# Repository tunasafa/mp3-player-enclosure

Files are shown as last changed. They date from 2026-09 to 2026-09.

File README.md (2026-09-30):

# mytunas — MP3 player enclosures

> *I got tired of renting my music.*

This repository contains **two current enclosure models** for the same offline MP3 player project. Both are fit and mechanical prototypes; physical hardware qualification, electronics integration and production release are still outstanding.

## Current models

| Model | Controls and display | Exterior | Current files |
|---|---|---:|---|
| **P04 clickwheel player** | 4th-generation monochrome clickwheel, 2.0-inch landscape display, Adafruit #6309 headphone output | **115 × 60 × 12.9 mm** | [Model README](revision_04/README.md) · [interactive viewer](https://tunasafa.github.io/mp3-player-enclosure/revision_04/preview.html) |
| **Model 02 touchscreen player** | 2.4-inch landscape capacitive touchscreen, two battery allocations, Adafruit #6309 headphone output | **64 × 128 × 8.3 mm** | [Model README](touchscreen_02/README.md) · [interactive viewer](https://tunasafa.github.io/mp3-player-enclosure/touchscreen_02/preview.html) |

The P04 branch uses two printed shells, a protected 503040 battery allocation and the intact DAC with its headphone socket. Model 02 uses the M02-03 metal finish, a continuous PA12 frame, a welded display carrier, removable board supports and the DAC jack at the bottom. The detailed model pages are the source of truth for dimensions, parts, evidence and remaining checks.

## P04 clickwheel player

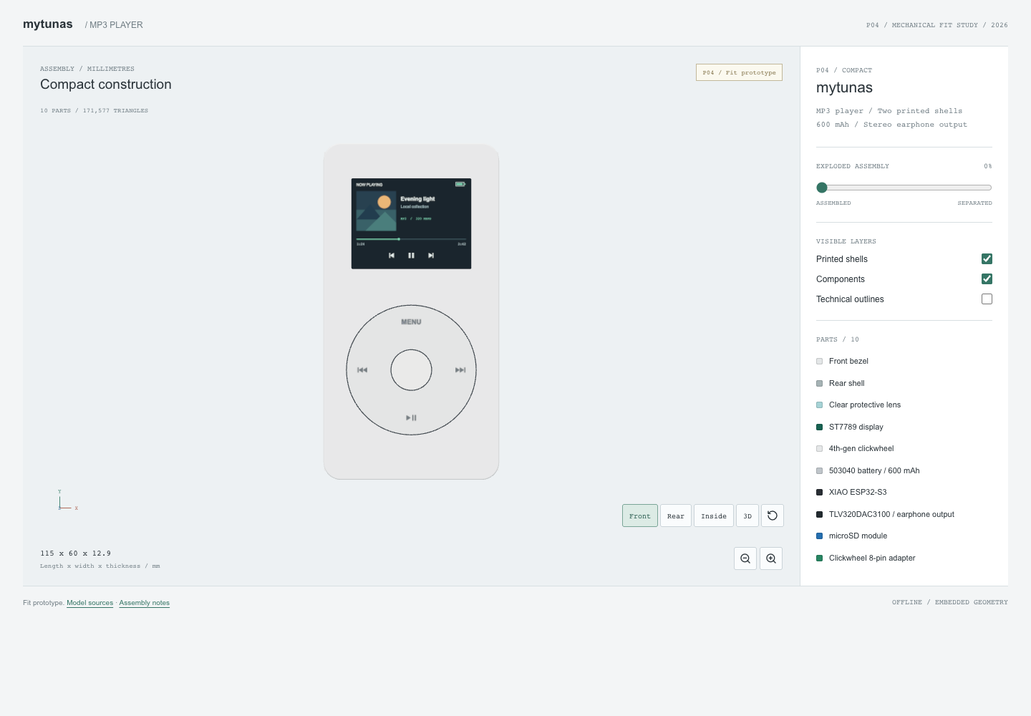
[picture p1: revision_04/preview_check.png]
P04 clickwheel player interactive preview


**[Open the P04 interactive 3D viewer](https://tunasafa.github.io/mp3-player-enclosure/revision_04/preview.html)**

The P04 layout keeps the 600 mAh battery below the display, behind the wheel. The DAC is at the upper left, flipped relative to the earlier layout, with its components toward the rear and its headphone socket at the top. USB and microSD use close-fitting side openings. These openings and the shell seam are unsealed; no IP rating is claimed.

Read the [P04 model notes](revision_04/README.md), [hardware and connection notes](revision_04/HARDWARE_NOTES.md), [BOM](revision_04/BOM.csv), [validation report](revision_04/validation.json) and [dimensioned overview](revision_04/design_overview.pdf). Print files are under [`revision_04/designs/P04_compact/STL/`](revision_04/designs/P04_compact/STL/).

## Model 02 touchscreen player

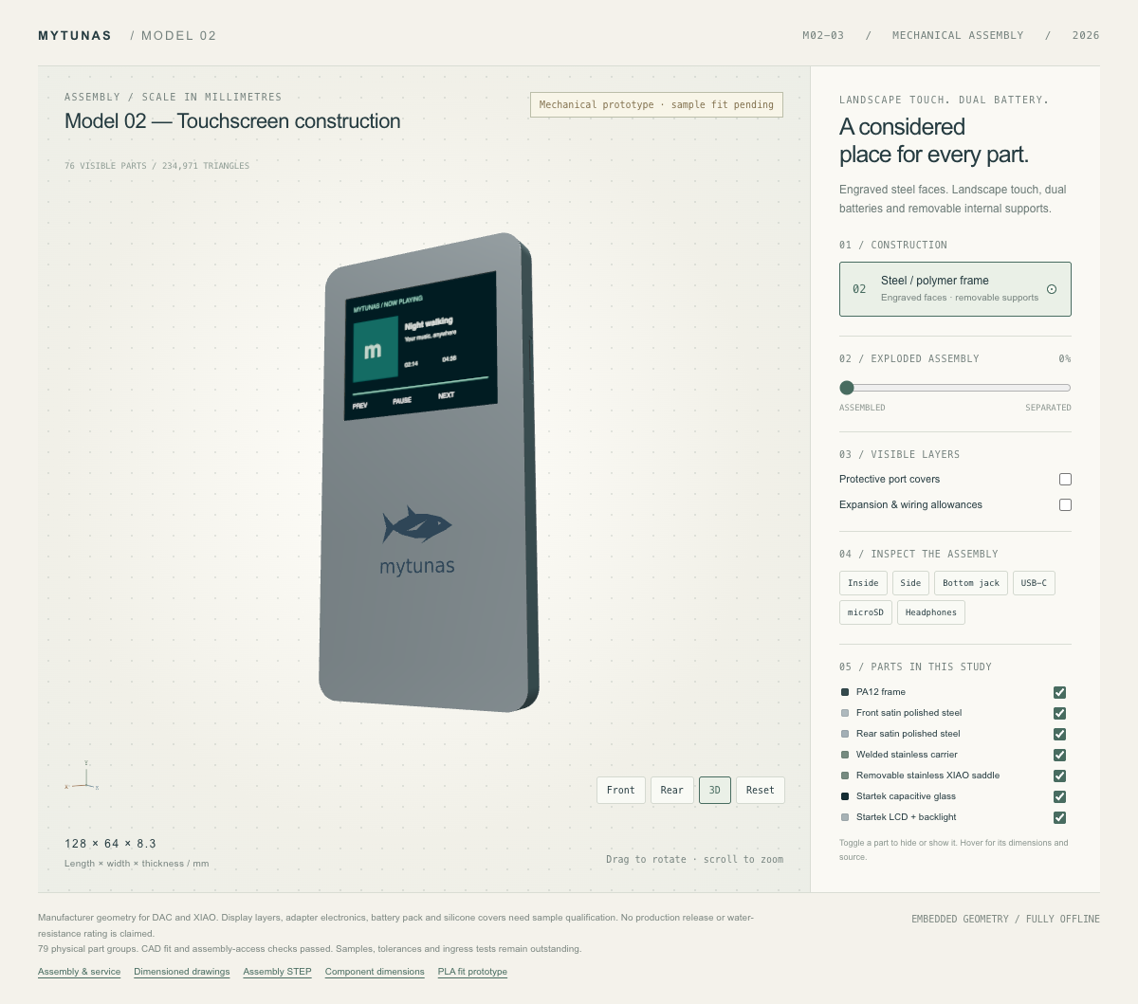
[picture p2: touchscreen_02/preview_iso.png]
Model 02 touchscreen player interactive preview


**[Open the Model 02 interactive 3D viewer](https://tunasafa.github.io/mp3-player-enclosure/touchscreen_02/preview.html)**

The current M02-03 layout uses the 2.4-inch Startek touchscreen allocation, two battery envelopes in an L arrangement, the intact Adafruit DAC with its original jack at the bottom, engraved steel faces, a welded internal carrier and serviceable supports. The screen sample, combined 1S2P battery, interface PCB and physical tolerances remain to be qualified. The port covers are prototype references, so no water-resistance rating is claimed.

Read the [Model 02 notes](touchscreen_02/README.md), [assembly and service sequence](touchscreen_02/ASSEMBLY.md), [component evidence](touchscreen_02/COMPONENT_DIMENSIONS.md), [release checklist](touchscreen_02/RELEASE_CHECKLIST.md), [BOM](touchscreen_02/BOM.csv), [validation report](touchscreen_02/validation.json) and [dimensioned drawings](touchscreen_02/drawings.pdf).

The [M02-P01 PLA fit prototype](touchscreen_02/pla_fit/README.md) is a separate MK3S+ branch with the same exterior and component positions, four printed assembly parts and two releasable snaps. [Open the PLA assembly](touchscreen_02/pla_fit/preview.html) or [download the unsliced print plate](touchscreen_02/pla_fit/M02-P01_MK3S_PLA_UNSLICED.3mf). Physical printing and latch fit remain to be tested.

## Why this exists

Every month, another €10 disappears into a streaming service that decides what I can listen to, when, and on which devices. Skip limits, offline restrictions, algorithms picking songs for me, entire albums vanishing from catalogs overnight because some licensing deal fell through. And if I ever stop paying? Everything is gone.

I used to *own* music. I had files. I had albums. I could play them on whatever I wanted, wherever I wanted, forever. No subscription. No internet required. No corporation standing between me and a song.

So I'm building my own player: a physical device with a screen, a clickwheel or touchscreen, a headphone jack and a microSD card full of music that belongs to me. No accounts, no telemetry, no monthly fee.

## Repository map

```text
revision_04/       P04 clickwheel player; current compact printed-shell branch
touchscreen_02/    Model 02 touchscreen player; current M02-03 mechanical branch
touchscreen_01/    Superseded T02 touchscreen prototype and hardware audit
touchscreen_metal/ T03 construction reference and packing studies
```

The historical touchscreen branches are retained to document design decisions. Their dimensions, parts and validation reports do not replace the two current model pages above. The `revision_04/studies/` folders likewise contain rejected or conditional P04 experiments.

## Rebuild

Each model has its own rebuild and validation instructions. The short forms below assume the repository's existing `.venv` and Node dependencies:

```sh
# P04 clickwheel player
.venv/bin/python revision_04/build.py
.venv/bin/python revision_04/make_viewer.py
node revision_04/verify_viewer.mjs

# Model 02 touchscreen player
.venv/bin/python touchscreen_02/build.py
.venv/bin/python touchscreen_02/verify_fit.py
node touchscreen_02/verify_viewer.mjs
```

The generated viewers are standalone HTML files and can be opened locally. GitHub's source-file view does not run them; use the Pages links or download the HTML first.

## Project status

The CAD and browser checks validate digital geometry, mesh validity, clearances and viewer behavior. They do not prove purchased-component fit, flex routing, electrical compatibility, battery safety, structural durability, ingress protection or production readiness. See the [P04 status](revision_04/README.md#status) and [Model 02 release gates](touchscreen_02/RELEASE_CHECKLIST.md) before fabricating parts.

This is a personal hardware design project. Third-party CAD attribution and license notes are kept with each model's `vendor/` directory.

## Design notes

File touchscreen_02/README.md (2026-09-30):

# Model 02 — current serviceable touchscreen player

**One of the two current enclosure models.** The other is [P04, the clickwheel player](../revision_04/README.md).

**PLA fit-prototype branch:** [M02-P01 print/assembly instructions](pla_fit/README.md) · [interactive screwless assembly](pla_fit/preview.html) · [MK3S+ print plate](pla_fit/M02-P01_MK3S_PLA_UNSLICED.3mf). This separate branch keeps the 64 × 128 × 8.3 mm envelope and component positions, using four printed parts and two release snaps. The M02-03 metal design below remains the reference; PLA snap performance still needs a coupon trial.

**64 × 128 × 8.3 mm**, with the 2.4-inch landscape touchscreen, two battery allocations and the intact Adafruit DAC's original headphone jack at the bottom. M02-03 uses the T03 metal finish, original bluefin engravings and mechanically removable supports in the nominal enclosure assembly.

[Interactive viewer after GitHub Pages deployment](https://tunasafa.github.io/mp3-player-enclosure/touchscreen_02/preview.html) · [Local/offline viewer](preview.html) · [Dimensioned drawing set](drawings.pdf) · [Assembly STEP](designs/M02_03/assembly_NOMINAL.step) · [Every part's measurements](measurements.csv) · [Validation](validation.json)

The mechanical prototype includes engraved steel faces, a continuous polymer frame, 13 metal threaded insert seats, a welded steel display carrier with cross ribs and access windows, a two-screw XIAO saddle, rear-fastened steel DAC columns with insulating locating seats, battery guides, insulating pads, SD and display-interface mounting lands, gaskets and flush removable port-cover prototypes. The viewer uses the same physical geometry as the CAD checks and STEP export.

**This is not a production release.** The display drawing/flex and final battery pack have not been qualified; the interface PCB is not routed. Physical tolerances, retention, plate deflection, charging and ingress still require testing. The [release checklist](RELEASE_CHECKLIST.md) makes these remaining steps explicit. Detailed geometry is not evidence that these tests have passed.

## Files to use

| Deliverable | Purpose |
|---|---|
| `designs/M02_03/assembly_NOMINAL.step` | Current assembly, physical parts only |
| `designs/M02_03/reserved_spaces_REFERENCE.step` | Unoccupied expansion and routing allocations; never manufacture these solids |
| `designs/M02_03/*.step` | Individual case, support and cover geometry |
| `designs/M02_03/STL/midframe_BEFORE_HEAT_INSERTS_PA12_FIT_PROTOTYPE.stl` | Frame before insert installation, with 2.15 mm pilots, positioned on Z0 |
| `designs/M02_03/midframe.step` | Installed frame with polymer displaced around inserts; do not use as the pre-installation print |
| `designs/M02_03/STL/*METAL_REFERENCE.stl` | Metal shape references; not thin plastic print instructions |
| `designs/M02_03/STL/*SILICONE_REFERENCE.stl` | Installed/compressed cover references; retention/mold design unqualified |
| `designs/M02_03/profiles/*.dxf` | Millimetre profiles for specifically named flat layers; rear profile is before countersinking |
| `drawings.pdf`, `measurements.csv`, `BOM.csv` | Dimensions, coordinates, materials and part status |
| `ASSEMBLY.md` | Installation and service sequence, including board insertion paths |
| `COMPONENT_DIMENSIONS.md` | Evidence and uncertainty for bought and custom parts |
| `assets/front_engraving.svg`, `assets/rear_engraving.svg` | Original vector engraving artwork in face coordinates |

`packing_REFERENCE_ONLY.step` remains a compatibility alias for the current complete assembly. The GitHub source-file view will not run an HTML viewer; open the Pages link or the downloaded HTML in a browser.

The explosion slider, part toggles, covers and routing allowances preserve your current rotation, pan and zoom. Resizing the window also preserves the camera position. Choose a view preset or Reset when you want to reframe the assembly.

The current preview uses T03's darker metal palette and surface response, with the M02-03 engravings retained. This appearance setting is defined in `viewer.js`; it does not change the validated geometry.

## Dimensions and retention

| Feature | Current allocation |
|---|---|
| Exterior | 64.00 × 128.00 × 8.30 mm; R6 corners |
| Front and rear metal | 0.40 mm stainless each |
| Perimeter frame | Z0.55–7.75; raised rear compression stops to Z7.90; 1.60 mm walls |
| Display carrier | 59 × 50 mm; 0.20 mm web and 0.30 × 1.25 mm welded blades; four M1.4 × 3 screws |
| Main fasteners | Seven M1.6 × 5 nominal countersunk screws into PEM MSIB-M1.6-300 insert allocations |
| Internal threads | Six PEM MSIB-M1.4-150 insert allocations for carrier and XIAO saddle |
| DAC attachment | Three custom threaded steel columns and insulating locating seats; three rear M1.4 × 3 countersunk screws |
| Engravings | 0.03 mm nominal depth on front and rear; original tuna mark and model/revision text |
| Battery A | 37 × 25.5 × 5.2 mm; centre X−10.5, Y−6; underside Z0.70 |
| Battery B | 25.5 × 37 × 5.2 mm; centre X−15.75, Y−40.5; underside Z0.70 |
| Battery rear allowance | 1.93 mm to liner; 1.70 mm reserved for expansion |
| DAC | Original manufacturer STEP rotated −90° around Z; full published 7.1 mm height retained |
| DAC rear clearance | 0.18 mm to dielectric liner |
| USB-C mouth | X31.6000, Y−9.9927, Z3.6050; exact Seeed rim plus 0.15 mm radial allowance |
| Jack mouth | X18.8592, Y−63.6000, Z4.4225; 5.00 mm case aperture |
| SD mouth | X−31.6000, Y29.0000, Z6.4000; 11.50 × 1.50 mm slot |

There are no straps across the pouches. Separate replaceable insulating adhesive pads retain the batteries, and frame rails provide lateral clearance. The DAC rests on a removable dielectric sheet; its original holes receive insulating locating seats under rear-fastened steel columns. The XIAO rests on a removable dielectric seat and is held by a two-screw steel saddle with a shield cushion. The small removable XIAO side stop still uses a replaceable adhesive pad.

The revised carrier replaces four glued rib/bond parts with a connected welded steel structure. Its four screws and the two saddle screws use metal insert threads. [PEM MSIB-M1.6-300](https://www.pemnet.com/products/product-finder/msib-m1-6-300/) and [MSIB-M1.4-150](https://www.pemnet.com/products/product-finder/msib-m1-4-150/) have published 2.5 mm nominal outside diameters and 2.15 mm installation holes. The CAD uses smooth dimensional envelopes; actual knurls and thread helices are omitted. Supplier installation forces measured in other plastics do not establish PA12 performance. Qualify the chosen frame process, insert installation and torque on coupons.

These changes provide defined retention and service access; they do not establish a multi-year lifetime. Batteries, display bonding and the provisional SD/interface boards still need replaceable adhesive interfaces. XIAO withdrawal requires removing battery A first because the inward USB withdrawal path crosses its installed envelope. See the explicit service order rather than assuming every board lifts out independently.

## Display and electronics evidence

Startek lists [KD024QVFMA020-C003A](https://www.startek-lcd.com/product/474-KD024QVFMA020-C003A-2.4-inch-240x320-ST7789V-IPS-LCD-module-with-build-in-capacitive-touch-panel.html) as a 240 × 320 IPS panel with ST7789V, FT6336G touch, a 42.92 × 60.26 × 3.75 mm total outline, a 45-pin 0.5 mm LCD flex, 3.3 V module input and an 80 mA backlight. Its touch specification lists a 42.62 × 59.96 × 1.25 mm G+F assembly. The model uses that touch outline and the remaining 2.50 mm for the LCD. Adhesive split, active-area offset, maximum tolerances and actual folded tails still require the supplier drawing. The product-page drawing link returned 404 during this work; the available stock-policy image is not a mechanical drawing.

The 45-pin interface replaces the inappropriate 15-pin watch connector allocation. A larger 15 × 32 mm interface board is allocated behind the screen, with a 45-pin ZIF envelope. Its schematic and PCB layout are not complete. The SD board/socket also remain conservative custom-board allocations. These electronic assemblies must be completed before ordering the enclosure as production tooling.

Startek's [general sales policy](https://www.startek-lcd.com/?no=1) allows small orders; this is not confirmation of current stock for the exact suffix. The [supplier inquiry](SUPPLIER_INQUIRY.md) remains unsent.

## Battery and power

The cell allocations use the published maximum finished-pack dimensions for DTP502535, referenced by [SparkFun PRT-13851](https://www.sparkfun.com/lithium-ion-battery-400mah.html) and its [manufacturer drawing](https://www.digikey.com/htmldatasheets/production/2065026/0/0/1/prt-13851.pdf). Two 400 mAh-class cells suggest an **800 mAh target**. A supplier-designed matched **1S2P** pack, its protection and its final lead layout are still required. The model is not an instruction to connect two retail protected packs together.

Confirm the chosen pack against the XIAO charger, temperature limits, charge termination and operation while charging. The XIAO's supported battery input is a single rechargeable 3.7 V lithium cell/parallel group; do not use a two-cell series pack. [Seeed battery documentation](https://wiki.seeedstudio.com/xiao_esp32s3_getting_started/).

The metal enclosure has no qualified RF path. Wi-Fi/Bluetooth antenna placement and performance are outside this mechanical release; the default design is a local SD-based player. Touch wake, power-off behavior and battery measurement also need firmware/electrical verification.

## Ports and sealing

All three case apertures are physically cut and aligned to their corresponding component mouths. USB follows the actual eight-edge Seeed rim with 0.15 mm radial clearance; the 5.00 mm jack opening allows 0.20 mm around the CAD flange; the SD slot allows 0.25 mm per side around the card. Zero-clearance fits are not specified: they would not accommodate real manufacturing variation. Blind internal pockets accommodate the connector bodies while preserving an exterior lip. Flush silicone-cover prototypes close the ports without extending the exterior dimensions. The viewer starts with covers removed and provides dedicated USB-C, SD and jack closeups. Fit the covers with the checkbox when reviewing the closed enclosure.

The covers are modeled in their installed/compressed shape, with separate recessed sealing lands. Their thin flanges, retention, free-state dimensions, material hardness and mold process have not been validated. They are prototype references, not proven waterproof plugs. The XIAO USB socket and Adafruit headphone jack are not established as sealed receptacles. **No IP or water-resistance rating is claimed**, especially with any cover removed.

## Verification and rebuild

The build checks all modeled physical-part intersections, all reservation collisions, exterior containment, unobstructed case ports with covers removed, rear loading of the display and batteries, sampled recessed/lowered/sliding board insertion, screwdriver access, nominal support contact, and valid single-body watertight structural/cover meshes. Deliberate collision and blocked-port probes test failure detection. Browser tests check the same CAD mesh bounds and physical mesh counts, inside/outside views, exploded assembly, covers, mobile rendering and the old viewer redirect.

From the repository root, using the existing CadQuery environment and `revision_04` npm dependencies:

```sh
.venv/bin/python touchscreen_02/make_branding.py
.venv/bin/python touchscreen_02/build.py
.venv/bin/python touchscreen_02/verify_fit.py
.venv/bin/python touchscreen_02/make_drawings.py
node touchscreen_02/verify_viewer.mjs
.venv/bin/python touchscreen_02/package_design.py
```

A failed build writes its report and refuses new CAD/viewer exports. Manufacturing release depends on the checklist, not just `validation.json` reporting a nominal fit.

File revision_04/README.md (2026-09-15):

# mytunas / P04 — current clickwheel player

**One of the two current enclosure models.** The other is [Model 02, the touchscreen player](../touchscreen_02/README.md).

**115 x 60 x 12.9 mm enclosure**, 0.2 mm thinner than the 13.1 mm baseline, with no footprint increase. The selected hardware is unchanged. The protected 600 mAh battery is entirely below the display, behind the wheel. The DAC is at the upper left, flipped 180 degrees about Y relative to the original 13.1 mm layout, with its components facing the rear and headphone socket at the top.

Open [the interactive preview](preview.html), [component layout](internal_layout.png), or [shell drawings](design_overview.pdf). See [BOM](BOM.csv), [hardware notes](HARDWARE_NOTES.md) and [model sources](vendor/README.md).

The detached-jack experiment has been withdrawn from this build: it added wiring and retention without reducing the complete case. The intact DAC and onboard socket are restored. See [thickness decision and thinner-battery candidate](THICKNESS_REVIEW.md) for the two limiting stacks and the conditions under which a future change would help.

## Thin arrangement

| Item | Current allocation |
|---|---|
| Battery | 40 x 30 x 5 mm; center (0, -8), Z 5.0-10.0; below LCD |
| DAC | 25.4 x 33.7 x 7.1 mm; center (-9.3, 40.763), Z 4.3-11.4 |
| XIAO | Upper right, center (17.996, 30), Z 4.3; USB mouth nominally flush |
| microSD | Lower right, center (17.7, -36), Z 5.0 |
| Wheel adapter | Lower left, center (-13, -37), Z 5.0 |
| Battery connector | Above/right of battery, center (18, 15.5) |

The battery's top edge is Y7 and the LCD's bottom edge is Y10, so they do not overlap in projection. The full 5 mm cell thickness and the **original 1.7 mm rear allowance** are retained. No battery space was traded away to obtain the new thickness.

A 0.2 mm-deep local LCD seating pocket leaves **1.0 mm of front skin** beneath its perimeter. The LCD sits at Z1.2 instead of Z1.4, preserving 0.2 mm adhesive space and 0.5 mm to the lens. The complete wheel moves forward 0.2 mm, retaining 0.2 mm beneath its backing. Its representative center button is about 0.06 mm proud of the front: shell depth is 12.9 mm, illustrated button-to-back span about 12.96 mm. Exact wheel geometry remains unmeasured.

The two limiting stacks are now:

- LCD: front Z1.2 + 2.8 LCD + 0.3 gap + 7.1 DAC + 0.3 gap + 1.2 rear skin = **12.9 mm**.
- Wheel: front Z1.4 + 3.3 backing + 0.3 gap + 5.0 cell + 1.7 rear allowance + 1.2 skin = **12.9 mm**.

The DAC still shares the upper LCD area. Behind the thicker wheel it would require 13.6 mm even with the new seat. The rotated board alone cannot reduce its height. Both face orientations were checked at the upper location; the released version is rear-facing as requested. It retains the [manufacturer's published 7.1 mm height](https://www.adafruit.com/product/6309), rather than substituting the smaller nominal STEP height of 6.3725 mm.

These are lower bounds for this layered arrangement and the retained allowances, not a proof of globally optimal packing. Further reductions need measured component maxima, revised allowances or a different enclosure architecture. No board trimming, connector removal, battery compression or electrical substitutions are made.

The original and older compact comparison baselines remain in the repository. `validation.json.requested_repack` compares against both the 13.1 mm target and the rejected 13.8 mm battery-behind-display version. The older `studies/dac_orientation/` folder is historical and excluded from the manufacturing ZIP.

## Tight connector openings

| Port | Exterior aperture | Seating |
|---|---|---|
| Headphones | 5.0 mm circular hole, top | Around the manufacturer's 4.6 mm barrel; mouth 0.05 mm recessed |
| USB-C | 9.4 x 3.7 mm rounded opening, upper right | Around the actual 8.94 x 3.21 mm outer metal mouth |
| microSD | 11.5 x 1.5 mm slit, lower right | Card-only access; cage concealed behind the wall |

The headphone socket axis is X-13.359, Y57.45, Z8.1725 mm. A blind shoulder relief behind the circular opening leaves a 0.7 mm outer lip; USB/card inner reliefs leave 0.9 mm. No oversized rectangular opening surrounds the jack. USB dimensions refer to its outer metal shell, not the smaller mating cavity.

The microSD module remains representative, not a verified manufacturer part. Check actual card travel, latch type, ejection and finger/tool access before final printing. No extra fingernail scoop is added; the narrow slit may require a thin nonconductive tool.

These apertures reduce exposed clearance but **do not seal the connectors or shell seam**. No dustproof, waterproof or IP rating is claimed.

## Print and assembly

The rear cap includes a centered **mytunas** wordmark beneath an original rounded waveform/m logo. Both are engraved **0.3 mm** into the exterior, leaving **0.9 mm** of the nominal 1.2 mm skin. The logo is 24 mm wide and the name is 26 mm wide. The actual recess is included in `rear_shell.step`, the printable `rear_shell.stl`, the assembly STEP and the preview. The viewer shades the recessed floor darker for legibility; a single-material print has the same plastic color throughout unless the recess is filled afterward.

The [logo artwork and generation prompt](assets/README.md) include the original PNG, outlined SVG, and CAD contours. Placement and depth are in `parameters.json` under `branding`. After changing the original logo or wordmark, run `make_branding.py` before rebuilding the CAD. The **Rear** preset shows the engraving; it disappears with the removed rear cap in **Inside** view.

Print `insert_and_clearance_fit_coupon.stl`, `front_bezel.stl`, and `rear_shell.stl` from `designs/P04_compact/STL/`, in millimetres at 100% scale. Exterior faces are already placed on the print bed at Z=0. Use STEP or `reference_only/` for assembly coordinates. Reference components are not printable hardware. Use this revision's matching front and rear shells; do not mix them with the preceding 13.1 mm or 13.8 mm versions or older 134 mm/110 mm layouts.

Main skins are 1.2 mm, with a 1.0 mm local LCD seat floor; walls are 1.6 mm and the seam gap is 0.2 mm. Four M2 × 7 mm screws retain the Z=10 mm seating plane, 2.2 mm nominal insert engagement and 1 mm pilot-bottom clearance. The Ø4.5 mm head wells are 2.9 mm deep. Insert pilots are provisionally Ø3.2 × 3.2 mm; verify against the selected inserts and coupon. Coupon upper-row pilot sizes are 3.0/3.1/3.2/3.3/3.4 mm; lower-row clearances are 2.1/2.2/2.3/2.4 mm. The lens DXF describes a 43 × 33 × 0.6 mm reference with 0.8 mm corner radii.

The rear cap has three DAC locating posts derived from the manufacturer's actual 2.5 mm mounting holes: two beside the jack and one at the opposite corner. The 2 mm locating pins enter those holes with nominal 0.25 mm radial clearance. Their 4 mm support lands stop 0.2 mm above the component-side PCB surface for an insulating adhesive layer. The inboard end stop opposes top-plug insertion; the posts avoid the modeled components. Fit and bond the board to those lands before use. Generic rear pads and insertion stops support the other boards with sample-fitted insulating adhesive or shims; their final thickness and loads remain unverified. No rigid pressure is applied to ICs or the battery pouch.

Battery side/end guides extend 2.3 mm inward from the rear skin and retain 0.8 mm lateral clearance. The cell has 1.7 mm nominal space to the rear skin and 0.3 mm to the wheel backing. Secure it with sample-qualified compliant adhesive, with no hard clamping or uncontrolled preload against the display. The advertised cell size does not establish maximum finished-pack thickness or expansion allowance. Verify PH 2.0 connector polarity before connection. Harness lanes, flex reserves and the connector pocket are empty-volume checks, not a fully routed harness.

## Electronics integration

The intended path is **XIAO I2S → TLV320DAC3100 → onboard headphone jack → earphones**. Supply the headphone-only board from regulated 3.3 V with common ground. It needs I²C configuration and reset in addition to the three I2S signals; firmware must select headphone output and disable its unused speaker amplifier. Follow [the connection notes](HARDWARE_NOTES.md) before wiring. No firmware implementation, power measurement, listening test or purchase was performed.

The landscape LCD, original monochrome clickwheel, one 8-pin adapter, XIAO and microSD hardware are retained with new placements. No antenna, physical power switch, 15-pin adapters or middle carrier are added. Physical LCD/wheel dimensions, flex bends, battery specifications, plug fit, retention and the complete GPIO/sleep implementation remain open fit-prototype work.

The provisional clickwheel setup ties **CFG1 high for event-only mode**, with external pull-ups on SCK and MOSI and BTN1 reserved as a wake candidate. Grounding CFG1 selects continuous/command mode. The supporting research used a Photo/color wheel; validate it on the selected monochrome assembly. The supplied Your Cee adapter listing specifies **0.5 mm pitch on the obverse, 1.0 mm on the reverse, and 1.6 mm board thickness**, with an **8P variant** available. The user confirms an **included locking bottom-contact socket** and a **0.5 mm clickwheel pitch**: ribbon pads face the socket floor toward its supporting PCB, using the adapter's 0.5 mm 8P side. Verify the flex route, latch clearance and pin-1 continuity; PCB thickness alone does not establish assembled height. See the [clickwheel connection notes](HARDWARE_NOTES.md#clickwheel-adapter-and-pin-numbering) for protocol assumptions and the distinction between GPIO wake from sleep and restarting an unpowered controller.

## Rebuild and validation

### Detailed preview

The standalone [preview](preview.html) retains the original front/rear/inside/3D presets, orbit and zoom controls, exploded-assembly slider, part visibility and technical outlines. It displays colored manufacturer CAD for the DAC and XIAO, and detailed visual references for the LCD, clickwheel, battery, card module and FPC adapter. The screen UI sits on the LCD underneath the clear lens and follows the display when the assembly is exploded. Each component can be hidden independently. Visual approximations and attribution are documented in [model sources](vendor/README.md).

`make_components.py` imports manufacturer STEP assemblies with face/solid colors; `viewer.js` builds the remaining visual parts and renders them with Three.js. These do not overwrite the manufacturing STLs or change the fit-validation envelopes.

The browser verification also exports the seven detailed component STLs under `reference_only/` from the current preview geometry, in assembly coordinates, without screen/label planes. This keeps their placements and battery orientation in sync. They are visual references, not watertight printable hardware; the assembly STEP retains conservative fit envelopes. Packaging checks their hashes and rejects stale references.

Opening `preview.html` requires no server or network. To change the renderer or run browser checks, first install the pinned dependencies with `npm ci --prefix revision_04`. Rebuild the bundle with `npm run build --prefix revision_04`; `make_viewer.py` also rebuilds it automatically when `viewer.js` is newer. An unchanged bundled renderer needs no npm installation to regenerate the HTML.

From the project root:

```sh
.venv/bin/python revision_04/build.py
.venv/bin/python revision_04/make_viewer.py
.venv/bin/python revision_04/make_drawings.py
.venv/bin/python revision_04/make_layout.py
node revision_04/verify_viewer.mjs
.venv/bin/python revision_04/package_designs.py
```

In the standalone package, create a Python environment, install `requirements.txt`, and run the scripts without the `revision_04/` prefix. The Playwright browser check needs Node 22+, the npm dependencies above, and Brave, or a Chromium executable supplied through `P04_BROWSER_PATH`.

`validation.json` reports shell validity, watertight single-body print meshes, conservative component-to-component and physical shell/routing collisions, depth/side clearances, vendor-model containment and socket alignment. `viewer_validation.json` records preview controls, labels and desktop/mobile rendering. Packaging rejects stale input/preview hashes and verifies mesh validity, ZIP CRCs and SHA-256 contents. These checks validate the digital prototype; they do not establish physical hardware fit.

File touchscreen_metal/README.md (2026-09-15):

# T03 — historical thin metal touchscreen reference

**Reference only; this is not one of the two current model branches.** The current touchscreen layout is [Model 02](../touchscreen_02/README.md): 2.4-inch screen, two batteries and bottom jack at the same 64 × 128 × 8.3 mm exterior. This T03 assembly retains its earlier screen and single battery.

**64 × 128 × 8.3 mm.** An aggressive nominal fit prototype with the intact Adafruit #6309, its original jack facing the bottom, the 5 mm battery above it, and the landscape touchscreen at the top. USB faces right; microSD faces left. The display interface is now beside the screen, with proposed side-entry ribbon routes.

[Interactive viewer on GitHub Pages](https://tunasafa.github.io/mp3-player-enclosure/touchscreen_metal/preview.html) · [Dimensioned drawing](design_overview.pdf) · [Fit report](validation.json) · [Thinner options study](THICKNESS_STUDY.md)

[Side-jack / 2.4-inch / L-battery packing study](studies/side_jack/README.md) — conditional alternative with its own offline 3D viewer. Startek sample stock and the finished battery pack are unconfirmed; this does not replace the T03 assembly.

The Pages link serves this version after these files are deployed. For immediate local use, open `preview.html` in a browser. GitHub's source-file page does not run HTML.

## Construction and actual thickness budget

| Layer at the DAC | mm |
|---|---:|
| Stainless front face | 0.40 |
| Dielectric / underside allocation | 0.15 |
| Full published Adafruit board height | 7.10 |
| Minimum free clearance | 0.15 |
| Rear dielectric liner | 0.07 |
| Stainless rear face | 0.40 |
| Calculated nominal minimum | **8.27** |
| Modeled exterior thickness | **8.30** |

The completed model has **0.18 mm clearance to the rear liner**, above the full 7.1 mm DAC allowance. A smaller STEP height was not substituted. The 5 mm battery retains **2.13 mm to the liner**, including an untouched 1.7 mm reserve. Neither screen nor audio board is stacked over the battery.

The 8.3 mm thickness is 20.2% below T02's 10.4 mm and 35.7% below P04's 12.9 mm. Width grows from 52 to 64 mm and length changes from 132 to 128 mm; volume is only about 4.7% below T02. This is a thinner, wider player, not a uniformly smaller one.

The steel faces alone weigh approximately 48 g using a planning density of 8 g/cm³ and their CAD volumes. The thinner construction trades weight and fabrication complexity for thickness. No plate-deflection or drop-test result is claimed.

## Parts and fastening

- Separate 0.4 mm front and rear steel faces and a 0.4 mm metal display retainer; profile DXFs and 3D STEPs are provided.
- Separate PA12 frame candidate with connected guides, port walls, screw towers and interface-board lands. This is the part intended for polymer prototype printing.
- Six flush countersunk M1.6 × 5 nominal case screws; two small M1 carrier screws. Screw roots and nominal heads are visual/fit references. Qualify an actual screw drawing and polymer pilot fit before fabrication.
- Front perimeter bond and rear perimeter gasket, each 0.15 mm nominal. The front plate is bonded to the frame; rear screws make the component bay serviceable.
- Dielectric pads under all boards and a 0.07 mm rear liner. The battery has a separate 0.3 mm insulating pad.
- Three nonconductive rear spacers engage the Adafruit board's original mounting holes. Edge guides oppose headphone-plug insertion; the rear spacers capture the PCB against its insulated seat. Spacer attachment and clamp load require a physical trial.
- Tight 5 mm bottom jack aperture, 9.24 × 3.51 mm USB aperture and 11.5 × 1.5 mm card slot. The USB opening now uses the actual eight-edge Seeed connector shell profile, offset outward by 0.15 mm for assembly. Its centre also comes from that rim, replacing the previous approximate point. Internal reliefs stop 1 mm short of the outside. Ports remain unsealed; the perimeter gasket does not establish an IP rating. See the [port-sealing requirements](studies/side_jack/README.md#port-protection).

Metal reference STLs are named `*_METAL_REFERENCE.stl`; they are not thin plastic shells to print. Only `midframe_FIT_PROTOTYPE.stl` is the polymer frame candidate. The rear cutting-profile DXF uses 2.4 mm underside pilot holes. The STEP defines the subsequent 90° countersinks to 3.2 mm at the top face. Artwork is separated into `rear_marking_ONLY.dxf` and must not be through-cut. Metal cutting, countersinking, edge finishing, bonding and flatness control are separate operations.

## Validation and limits

The CAD build rejects physical inter-part intersections, reserved-volume intersections, protruding components, blocked port paths, an obstructed glass rear-loading sweep, and invalid/disconnected/non-watertight structural parts. CAD, STEP and viewer share the original board transforms and common geometry. Browser checks compare physical mesh counts and bounds and exercise desktop/mobile, inside, ports and exploded views. Fault-injection checks deliberately move the battery into the DAC and block each port.

**Nominal clearance is not a tolerance analysis.** At only 0.18 mm above the maximum DAC allowance, plate flatness, thickness variation, adhesive variation, solder, mounting error and load deflection matter. `qualified_for_fabrication` is explicitly false. The rear liner must never be treated as spare mechanical clearance. The next physical checks are finished-board measurements, an insulated mounting trial, sample plate deflection, screw/clamp behavior and repeated plug insertion.

The display glass outline and thickness are user estimates; tail lengths, stiffeners and latches remain unmeasured. The 12 × 24 mm interface PCB is a custom placement allocation, not a routed or manufactured board. The SD assembly remains representative. Firmware, power budget, pinout and touch wake have not been verified by this mechanical work; see the [hardware audit](../touchscreen_01/HARDWARE_AUDIT.md).

## Rebuild

From the repository root, using the existing CadQuery environment and P04's pinned viewer dependencies:

```sh
.venv/bin/python touchscreen_metal/build.py
.venv/bin/python touchscreen_metal/verify_fit.py
.venv/bin/python touchscreen_metal/make_viewer.py
.venv/bin/python touchscreen_metal/make_drawings.py
node touchscreen_metal/verify_viewer.mjs
```

Current output: `designs/T03_metal/`. The previous [T02 design](../touchscreen_01/README.md) remains intact. Vendor attribution and licenses are in [vendor notes](vendor/README.md).

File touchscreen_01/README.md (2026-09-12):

# Superseded T02 — historical bottom-jack prototype

**Superseded by the selected [64 × 128 × 8.3 mm Model 02](../touchscreen_02/README.md), with two batteries and a 2.4-inch screen.** These files retain the older geometry for reference; they are not the current touchscreen design.

[Open the current Model 02](https://tunasafa.github.io/mp3-player-enclosure/touchscreen_02/preview.html) · [Historical T02 viewer](https://tunasafa.github.io/mp3-player-enclosure/touchscreen_01/historical_preview.html) · [Dimensioned drawing](design_overview.pdf) · [Fit report](validation.json)

The interactive link opens GitHub Pages. Opening `preview.html` in GitHub's code
view shows the source-file page, which cannot run the viewer and may report that
the file is too large. For offline viewing, download the HTML and open it in a browser.

**52 × 132 × 10.4 mm target.** Historical arrangement: landscape touchscreen at the top; microSD on the left and USB-C on the right beneath it; 503040 battery below them; intact Adafruit DAC at the bottom, with its original headphone jack facing down. There is no clickwheel and no added jack.

The Adafruit #6309 and XIAO use unscaled manufacturer STEP models. The same transforms and geometry feed collision checks, the STEP assembly and the viewer. The display layers follow the supplied 43 × 36 mm outer glass and estimated 3.3 mm assembled stack, including tape. The real photographs establish the right-side ribbon exits; their folded paths and connector housings remain proposed geometry.

## Thickness decision

The conditional lower bound is **10.4 mm**: DAC underside at Z=1.8 + the manufacturer's full 7.1 mm height + 0.3 mm rear clearance + 1.2 mm rear skin. The actual STEP is shorter than the published envelope; that difference is retained as allowance. At 10.2 mm only 0.1 mm would remain behind that envelope. This is the smallest thickness meeting these chosen clearances, not a claim that every possible architecture has been optimized.

The battery has its own bay, without the LCD or DAC above/below its pouch. Its nominal 5 mm thickness leaves 2.4 mm to the rear skin, including a reserved 1.7 mm. Compared with P04's 60 × 115 × 12.9 mm, T02 is 19.4% thinner and has approximately 19.8% less bounding-box volume. It is longer and narrower; footprint is almost unchanged.

## Ports and assembly

- USB-C: right wall; 9.4 × 3.7 mm exterior mouth, aligned to the actual Seeed connector.
- Headphones: bottom wall; 5 mm circular opening centered on the original Adafruit jack axis. No remote or duplicated socket.
- microSD: left wall; 11.5 × 1.5 mm exterior slot, aligned to a representative inserted card. The socket/module still needs a selected part drawing.
- Connector mouths are recessed 0.4 mm. Larger internal pockets stop 1 mm short of the exterior. They accommodate connector bodies without exposing a full rectangular PCB opening.
- A 0.6 mm thick glass ledge with 0.8 mm nominal border overlap, an overlapping shell seam, perimeter display adhesive, connected corner towers and four M1.6 × 5 screws. These are close-fitting **unsealed ports**, not a dustproof/waterproof rating.

Rear-load the screen into its adhesive seat first. Fit the removable display carrier and underside-mounted custom interface PCB, then connect the proposed inward-folding flexes. Seat the headerless XIAO, SD PCB and DAC in their bays; the DAC locators follow its real mounting holes. Fit the battery on insulating foam and route leads in the reserved side lanes. Close the rear and tighten the four screws after a fit coupon confirms the polymer pilot diameter. Screw CAD shows the root diameter; thread engagement is a fastening specification rather than collision-free thread geometry.

## Evidence and remaining measurements

`scan/newtouchscreendesign.png` preserves the supplied photo and `scan/newtouchscreenchart.png` the chart. The latest user message supersedes the photo's left-facing DAC arrangement. The chart's 45 × 50 mm screen placeholder and 52 × 162 mm outline were not treated as measurements; the user-confirmed 43 × 36 mm outer glass controls the screen allocation.

The panel corner radii, active border, exact ribbon lengths/stiffeners and bend limits, connector contact side, SD cage dimensions and finished battery protection end require sample verification. The interface PCB is a design allocation, not an existing manufactured board. Harness lanes reserve space but do not constitute a completed wiring loom. Panel controller and pin order remain unidentified; see the [hardware audit](HARDWARE_AUDIT.md).

## Rebuild and verify

From the repository root:

```sh
.venv/bin/python touchscreen_01/build.py
.venv/bin/python touchscreen_01/verify_fit.py
.venv/bin/python touchscreen_01/make_viewer.py
.venv/bin/python touchscreen_01/make_drawings.py
node touchscreen_01/verify_viewer.mjs
```

Current exports are under `designs/T02_bottom_jack/`: two shell STEP/STL files, a removable display carrier, and `assembly_NOMINAL_components.step`. Print files are **fit prototypes**, not a fabrication release. The older `designs/T01_concept/` files are superseded and contain known interference; do not print them.

The build fails on inter-part collisions, reserved-volume collisions, protruding components, blocked port cutters, a blocked glass insertion sweep, or disconnected/invalid/non-watertight printed parts. Viewer packaging rejects stale parameters or geometry sources. Browser checks compare every displayed physical part's bounds and mesh count with the validated data, then exercise desktop/mobile views and controls.

Manufacturer attribution and licenses remain in [vendor notes](vendor/README.md) and `../revision_04/vendor/`. P04 is maintained separately.

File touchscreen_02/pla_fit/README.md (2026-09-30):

# M02-P01 — screwless PLA fit prototype

This is the PLA fit-prototype branch of Touchscreen 02, designed for a **Prusa i3 MK3S+ with its stock 0.4 mm nozzle**. The nominal outside remains **64 × 128 × 8.30 mm, R6 corners**. All electronics, display and battery allocations retain their M02-03 positions and sizes. The metal design is preserved separately.

[Interactive assembly](preview.html) · [Unsliced print plate](M02-P01_MK3S_PLA_UNSLICED.3mf) · [Individual prints](parts/) · [CAD validation](validation.json) · [Metal reference](https://tunasafa.github.io/mp3-player-enclosure/touchscreen_02/preview.html)

## What changed

| Printed part | What it does |
|---|---|
| `front_tray` | One-piece front face, perimeter frame, battery fences, board guides, XIAO bed and rectangular carrier ledges. No threaded bosses. |
| `rear_lid` | Rear skin, two long snap tongues, locating skirt segments, carrier capture stops and integrated board restraints. |
| `carrier` | One-piece lift-out display/SD/interface support. The former welded steel web and separate stops become a 0.50 mm plastic deck with printable stiffeners and board pockets. |
| `xiao_gate` | Removable end stop installed after the USB board slides into its opening. Retained with a small strip of removable tape and captured by the lid. |

**Four assembly prints, zero screws, zero threaded inserts, two release snaps.** Three rounded rectangular DAC landing pads remain integrated into the lid at the original mounting annuli; they are not separate columns and contain no screw holes. A separate end stop on the lid prevents the DAC moving away from the headphone opening. The lid lifts vertically, allowing the boards to be removed in reverse assembly order.

The lid's two 18 mm long, 0.8 mm wide tongues flex **in the XY print plane**. Their ramped hooks engage windows in the top and bottom edges. Side slots free the beams from the rear skin. The receiving windows and slots are intentionally open, so the latch can be inspected and released. No sealing is claimed.

## Exact thickness comes with a tradeoff

Both face skins remain **0.40 mm**. They can be built as flat layers, but they are flexible and easily damaged compared with stainless steel. We have not made the case thicker, scaled the electronics, reduced the battery expansion space or moved the ports to make printing easier.

This is a delicate dimensional fixture, not a durable everyday PLA player enclosure. Print and try the latch coupon first. The geometry does not establish snap force, fatigue life, lid bow or resistance to plug loads. The screen and several electronics remain nominal allocations from the original project; fitting dummy shapes is not qualification of the actual components.

The plastic carrier occupies the former 0.20 mm steel web plus 0.30 mm board-pad stack. The SD/interface board support plane stays at **Z4.85**. The XIAO's former loose insulating bed is integrated into the tray, keeping its original **Z0.75** position. The underside of the rear skin stays **Z7.90**; omit the metal version's dielectric rear liner in this PLA branch. The full published 7.1 mm DAC height allocation is retained (nominal rear-skin clearance 0.25 mm). Do not use the smaller vendor mesh height to fill that space with reinforcement.

The 0.03 mm laser engravings and silicone port plugs are omitted from this fit fixture. They would not provide useful PLA fit evidence, and the full 0.4 mm skin thickness is retained for printing.

## Print on the MK3S+

The 3MF is an **unsliced geometry plate**, not a PrusaSlicer settings project or ready-to-run G-code. PrusaSlicer was not installed in the design workspace, so actual slicing and extrusion-path review remain to be done. The STL files are already oriented on Z0. The STEP files use assembly coordinates.

1. Open the 3MF in PrusaSlicer and select **Original Prusa i3 MK3S & MK3S+, 0.4 mm nozzle** and the profile for your PLA. Keep **100% scale**, in millimetres. Do not join the separate objects into a single mesh.
2. Print only `coupon_receiver` and `coupon_lid` first. Use the same filament, orientation and settings you will use for the case. These reproduce the actual latch geometry, including the release slot and retaining window.
3. Start with **0.05 mm layers and 0.20 mm first layer**, three perimeters, Arachne perimeter generation and 100% infill. The fine layers preserve the 0.35/0.50 mm support heights more closely. A 0.10 mm trial is faster but may quantize small support heights; review the sliced Z levels. Use your filament's normal PLA temperature profile.
4. Use a clean, calibrated bed. Check first-layer squish and elephant-foot compensation on the coupon; do not compensate by globally scaling the model. An outside-only brim may help the two large skins. Remove it without trimming mating edges.
5. **Tray: front exterior on the bed. Lid: rear exterior on the bed, pads pointing up. Carrier: flat underside on the bed. Gate: long side down.** The supplied files already use these orientations. Avoid auto-orienting the lid onto its pads.
6. Inspect every layer before printing: continuous 0.4 mm skins; open snap slots; both hooks; supported carrier fences; clear port roofs; all landing pads attached to the lid. The latch window is a short bridge, and the USB/SD openings also contain bridges. Try the coupon bridge first. If your printer needs support, paint it only under the relevant port roofs, and ensure it is removable without damage. Do not fill the latch slots with support.
7. Let the bed cool and release the thin skins gently. Do not pry up a 0.4 mm plate while it is strongly bonded. Measure the finished parts before fitting the screen or boards.

The full plate fits within the MK3S+ 250 × 210 mm bed. A geometry plate does not include purge lines, skirt or brim clearance; verify these with the selected printer profile. Printing coupons separately is strongly recommended even though they also appear on the complete plate.

Prusa references: [modelling thin features and tolerances](https://help.prusa3d.com/article/modeling-with-3d-printing-in-mind_164135), [PLA handling and limitations](https://help.prusa3d.com/article/pla_2062).

## Assembly

Coordinates use the original front exterior as Z0. The top is the screen end (+Y); the bottom is the headphone end (−Y).

1. **Trial the empty case and coupon.** Press the lid straight down at the two ends. Hooks should engage without bending the whole case or whitening the PLA. The rear should sit at its perimeter seat without bow. If the coupon is too tight, tune local mating clearance or printer compensation before printing the full case; do not force it.
2. **Fit the screen from the open rear.** Retain it with the original 0.15 mm perimeter adhesive allocation. Use the 0.05 mm display support cushion under the carrier; it is cut sheet/tape, not a printed layer. Actual glass support zones and flex routing still require the supplier drawing/sample.
3. **Install the XIAO before battery A and the gate.** Lower it with the USB connector 1.6 mm inward from final position, then slide it toward the right port. It rests on the integrated bed. Fit the printed gate on 0.15 mm removable tape. Preserve the original 0.30 mm shield-cushion allocation under the lid's clamp land.
4. **Install the DAC.** Lay the 0.15 mm underside dielectric sheet, lower the board 2 mm toward the screen from its final position, then slide the headphone jack into the bottom opening. The side fences locate it; the lid later supplies the end stop and vertical landing pads.
5. **Prepare the carrier outside the case.** Drop the SD board/socket and interface board into their pockets, without the microSD card. No 0.30 mm mounting pads are needed under these two boards: that space is now the thicker PLA carrier deck. Thread the actual tails through the retained access opening, then lower the loaded carrier onto its keyed shelves. Insert the card through the external slot afterwards.
6. **Fit the battery allocations/approved pack.** Use the original 0.30 mm replaceable pads, not rigid over-pouch clamps. The low fences limit lateral drift. Keep both **1.70 mm expansion reserves** and all harness routes empty. First perform the mechanical test with dummy battery shapes or disconnected hardware.
7. **Close the lid vertically.** Its landing pads restrain board lift, and its end stop prevents the DAC sliding back. Carrier and board capture stops have nominal small lift clearances rather than intentional component crushing. Ensure wires are clear of the snaps, rails and stop pads. Press near the two latch ends, not over the screen/batteries.
8. **Open by releasing the hooks inward.** The tongue tips are near X−5.2, Y±61.7. Use a fingernail or blunt pick in the rear relief slot/edge window to move each hook toward the centre by roughly 0.7 mm while lifting that end slightly. Do not lever against the screen or twist the thin skin. Practise on the coupon first. No repeated-cycle durability is established for PLA.

The only adhesive interfaces retained are screen bonding, battery retention, thin cushions/insulation, the pack-protection pad and the small removable gate pad. No structural glue is required to join the housing or carrier. Glue thickness is part of the fit stack; do not substitute thick foam tape indiscriminately.

## Acceptance record

Record physical results before considering a metal retention redesign. A passed CAD check is not a completed row here.

| Check | Physical result |
|---|---|
| Coupon closes and releases without cracks/whitening | Pending |
| 64 × 128 × 8.3 mm closed envelope, no rear bow | Pending |
| Actual screen and tails fit without stress | Pending |
| USB/headphone/card fully insert without case rubbing | Pending |
| Boards remain located under gentle handling/plug loads | Pending |
| Battery expansion spaces and lead paths remain empty | Pending |
| Parts survive careful reopening | Pending |

## Rebuild and validation

From the repository root:

```sh
.venv/bin/python touchscreen_02/pla_fit/build.py
.venv/bin/python touchscreen_02/pla_fit/verify_prints.py
node touchscreen_02/pla_fit/verify_viewer.mjs
.venv/bin/python touchscreen_02/pla_fit/package.py
```

The builder checks all physical part intersections, reserved volumes, original component identity, exterior containment, open ports, solid and mesh validity, sampled insertion paths, support contacts, and snap engagement/release geometry. Intentional snap approach interference is reported separately from rigid-body collisions. Geometry checks do not simulate printed-material flex or prove tolerance capability. The original metal source and exports are not rebuilt or overwritten.

The ZIP contains the geometry and a standalone offline viewer. Rebuilding the supplied source requires this repository and its existing CadQuery/Node dependencies; it is not a standalone source distribution.

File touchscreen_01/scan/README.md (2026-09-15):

# Historical T01 display scan inspection

This scan supports the superseded T01/T02 touchscreen work. It is not evidence for the current [Model 02 touchscreen](../../touchscreen_02/README.md), which uses a different 2.4-inch display allocation.

Source: user-uploaded `Scaniverse_2026_09_12_145606.obj` in
`revision_04/designs/P04_compact/reference_only/`. The original is unchanged.
Open the [inspection image](inspection.png), [interactive scan](preview.html),
[raw context image](raw_inspection.png) or [numeric report](scan_report.json).

The OBJ explicitly declares **metres**, so coordinates were multiplied by 1000
to inspect in millimetres. It contains 60,440 vertices and 115,278 triangles,
including a large support surface. The whole scan's approximately 235 × 193 mm
horizontal bounding box is therefore **not the display size**.

The analysis fits a plane to distant support-surface points, removes its small
tilt, approximately aligns the panel in plan by 31.5 degrees and crops a region
containing the body and folded ribbons. The 95th percentile residual on selected
support samples is about **0.54 mm**; this is observed surface variation, not a
certified uncertainty bound or calibration of the display dimensions.

With different height thresholds, the selected body region's 1st-to-99th-percentile
extent ranges roughly **34–37 mm across and 43.5–44.6 mm along**. The lower-height
thresholds include more edge material and some noise. This supports a preliminary
**38 × 46 mm packaging allowance**, not an exact glass outline. The body region
reaches approximately **4 mm above the fitted support plane**. Its hidden front
face, contact with the support and reflective-surface reconstruction are unknown;
surface height is not automatically physical panel thickness.

The scan-only study budgeted **4.2 mm for the combined display/touch stack**,
replacing the earlier 2.4 mm guess. The user then supplied a more specific
approximate stack: **0.25 mm cover + 0.70 mm sensor + 2.15 mm LCD/backlight =
3.10 mm, excluding tape**. The active model now adds **0.20 mm tape** for a
**3.30 mm panel assembly**, resulting in an **11.3 mm enclosure**. The same
battery thickness and rear allowance are retained. The 10.4 mm early and
12.2 mm scan-only parameter snapshots are retained as reference-only files.
The scan has not been rescaled to force agreement with the supplied thickness.
Neither source establishes a manufacturer-certified maximum stack dimension.

The mesh shows a body with rounded corners and folded tail regions extending
roughly 15–20 mm beyond its lower end. Parts of the folded region rise around
8–9 mm above the support. Scan smoothing joins thin surfaces and the support,
so the geometry cannot resolve individual conductors, 0.3 versus 0.5 mm pitch,
true film thickness, pin numbering, connector latch features or reliable bend
radii. We have **not** counted scan polygons as physical connector contacts.

The OBJ refers to `Scaniverse_2026_09_12_145606.mtl`, which is absent beside the
OBJ; the matching texture images are absent too. Consequently this inspection
is geometry-only. The original UV coordinates do not recover missing color or
printed flex codes. The scan does not establish the display controller or pinout.

The user subsequently specified **15-pin / 0.3 mm display FPC** and **6-pin /
0.5 mm touch FPC**. T01 uses these as supplied connector specifications; they
were not measured from the scan. Contact side and numbered pinout remain open.

The reported “4.3 × 3.6” is interpreted as centimetres (43 × 36 mm), and the
user has confirmed that it describes the entire outer glass surface. T01 now
uses a **36 × 43 mm** outer-glass allowance; the active-pixel aperture remains
unmeasured. The earlier 38 × 46 mm allowance remains only in the reference
snapshots.

The cropped PLY and viewer are inspection references, not a watertight physical
part used for collision certification. T01's validation uses conservative
parametric envelopes and explicit routing reserves. The ribbons will need a
new, physically checked fold into those reserves; their scanned resting pose
has not been demonstrated to fit the enclosure or reach either assumed ZIF.

To replace the provisional allowances, confirm outer glass width/height, total
stack thickness and one ribbon length with a ruler/caliper, then inspect the
matching material/texture files if available. Do not rescale the scan to match
a presumed 2.01-inch visible area; that would make the measurement circular.

Rebuild from the repository root:

```sh
.venv/bin/python touchscreen_01/scan/inspect_scan.py
.venv/bin/python touchscreen_01/scan/make_viewer.py
```

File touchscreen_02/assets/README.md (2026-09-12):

# Engraving artwork

The geometric bluefin silhouette was drawn as original vector contours for this device. `make_branding.py` generates `branding.json` and the two SVGs. Lettering is outlined DejaVu Sans; its license accompanies the artwork. No font installation is required to rebuild the CAD from the saved contours.

SVGs use face-view coordinates in millimetres inside the 64 × 128 mm exterior. The CAD mirrors X for the front face because the front is viewed along +Z, and leaves rear face coordinates unchanged. Engraving depth is 0.03 mm. The dark floor in the viewer is a non-overlapping subdivision of the actual engraved steel shape, not a floating decal. Steel faces retain 0.37 mm nominal material below their engraving.

Back identification is design information, not certification or a fabricated production serial number. The metal finish shown is a satin polished rendering target; surface finish samples and laser-mark contrast must be approved with the fabricator.

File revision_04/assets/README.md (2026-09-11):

# mytunas rear-cap branding

`mytunas-logo.png` is the original logo generated with the built-in imagegen tool.
Its transparent alpha channel is preserved. The symbol combines a lowercase m
with an audio waveform; it is placed above the outlined lowercase wordmark.

`mytunas-lockup.svg` is the scalable logo/name artwork. The same normalized
contours in `mytunas-branding.json` drive the real CAD recess. `make_branding.py`
traces the generated symbol and outlines the wordmark in DejaVu Sans Bold.
The SVG and CAD need no installed font to display the finished artwork.

The logo is 24 mm wide at rear-view (0, 6) mm; the name is 26 mm wide at
(0, -9) mm. Both are recessed 0.3 mm into the rear exterior, leaving 0.9 mm
of the 1.2 mm skin. The CAD mirrors X so the text reads correctly from the back.

## Generation prompt

Use case: logo-brand. Asset type: master symbol for a physical pocket MP3 player named mytunas, to be engraved into the middle of its rear cap. Create ONE original, exceptionally simple music-device brand mark: a compact lowercase m monogram formed by a bold continuous rounded ribbon, with two flowing arches that suggest an audio waveform. The mark should feel calm, distinctive, balanced and recognizable at 20 mm wide. Make the silhouette sturdy and engraving-friendly, with broad strokes, open negative spaces and gently rounded terminals. Flat solid pure black on a pure white background. Center the single symbol, filling roughly 65 percent of a square image. Perfectly orthographic flat logo art, crisp edges, no texture, no shadow, no gradient, no border, no 3D, no product mockup, no letters or text besides the abstract m symbol itself, no wordmark, no slogan, no Apple symbol, no fruit. Deliver one polished mark, not a sheet of variations.

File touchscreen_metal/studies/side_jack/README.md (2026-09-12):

# Conditional side-jack / Startek / L-battery packing study

**Exterior target remains 64 × 128 × 8.3 mm.** The nominal component and reserved-space checks pass. This is a component packing study, not a finished enclosure: retention, fasteners, real display tails, battery wiring and seals are not validated.

[Interactive viewer on GitHub Pages after deployment](https://tunasafa.github.io/mp3-player-enclosure/touchscreen_metal/studies/side_jack/preview.html) · [Offline viewer](preview.html) · [Reference STEP](packing_REFERENCE_ONLY.step) · [Packing report](validation.json)

Open the downloaded/local HTML directly in a browser. A GitHub source-file page will not run the viewer. The viewer bundles its dependencies and displays the same CAD meshes that were checked. Manufacturer boards have their original face colors; dimension envelopes are explicitly named. The blue box is an exterior limit, not a manufactured case.

## Procurement gate: Startek is provisional

Research date: 2026-09-12. Startek [lists KD024QVFMA020-C003A](https://www.startek-lcd.com/product/474-KD024QVFMA020-C003A-2.4-inch-240x320-ST7789V-IPS-LCD-module-with-build-in-capacitive-touch-panel.html): 240 × 320 IPS, ST7789V, FT6336G capacitive touch, SPI/MCU/RGB, complete nominal outline 42.92 × 60.26 × 3.75 mm. Landscape active area is 48.96 × 36.72 mm.

Its [company site](https://www.startek-lcd.com/?no=1) advertises one-piece orders and stocked samples. That is a general sales policy, not confirmation of this exact part's current inventory, price or lead time. No order or supplier message was sent. The user's condition “use it if sure it is for sale” is therefore not yet met for final component selection. A [ready-to-send inquiry](SUPPLIER_INQUIRY.md) records the missing information.

The model uses a square-corner maximum outline, not an invented detailed Startek model. Real flex, touch-controller protrusions, connector and adhesive tolerances are outstanding. The 60.26 mm landscape width leaves just 0.27 mm nominal clearance per side against the current 1.6 mm wall. Tolerance, insertion clearance and corner geometry must be confirmed before cutting metal.

## Placement

Coordinates are millimetres; XY is the face plane, Z runs from front to rear.

| Part | Placement / envelope | Evidence and limitation |
|---|---|---|
| Startek | 60.26 × 42.92 × 3.75; centre (0,35); Z 0.55 | Manufacturer nominal outline; procurement and detailed drawing pending |
| Adafruit #6309 | Whole original vendor STEP, jack toward right; mouth (31.6,-33.94085,4.42248) | No separate or relocated jack; full 7.1 mm published height also reserved |
| XIAO ESP32-S3 | Same unscaled board; centre Y -10; USB right | Solder, RF performance within metal case and final wiring unverified |
| Battery A allowance | 37 × 25.5 × 5.2; centre (-10.5,-6); Z 0.7 | Finished-pack dimension reference, not selected 1S2P subassembly |
| Battery B allowance | 25.5 × 37 × 5.2; centre (-15.75,-40.5); Z 0.7 | Identical capacity class, rotated in plane |
| SD assembly | Existing nominal assembly moved behind display; centre Y 29; Z 4.5 | Specific module still unselected; card slot would move with it |
| Interface allowance | 12 × 24 × 1.9; centre (21,38); Z 4.5 | Includes nominal underside parts; no routed PCB |

Each battery retains 1.93 mm to the rear liner, including a separate 1.7 mm expansion volume. The DAC retains 0.18 mm to that liner. Screen-to-electronics clearance is 0.20 mm. The existing T03 screw towers and retainers cannot simply be reused; this study does not count them as fitted.

The reference STEP includes the named reservation solids so they cannot silently disappear from downstream planning. They are not physical components. Browser controls hide/show them explicitly.

## Battery choice

The DTP502535 drawing supplied with [SparkFun PRT-13851](https://www.sparkfun.com/lithium-ion-battery-400mah.html) gives a 400 mAh pack maximum of **37 × 25.5 × 5.2 mm**, rather than assuming the bare-cell code means a complete 35 × 25 × 5 mm pack. [Manufacturer specification mirrored by DigiKey](https://www.digikey.com/htmldatasheets/production/2065026/0/0/1/prt-13851.pdf).

Two 400 mAh cells in a supplier-designed **1S2P** pack would target 800 mAh nominal at single-cell voltage, versus the current 600 mAh. This is a capacity target, not a selected pack, demonstrated runtime or authorization to parallel two SparkFun retail batteries. The protected retail-pack dimensions are only a conservative starting reference for the cells' allocation; a final combined pack drawing may differ.

Prefer a pack assembler to provide matched cells, the intended parallel interconnect, appropriate fault protection, insulation, lead strain relief and temperature sensing. Review the XIAO charging circuit, charging current, termination and operation while charging against that pack. Do not use a series connection on the XIAO's single-cell battery input. Jauch describes both [parallel capacity expansion and custom LiPo formats](https://www.jauch.com/downloadfile/5c5050fa5b6510e9a8ad76299baae4e53/white_paper_introduction_to_lipo_battery_technology_11-2018_en.pdf).

| Option | Assessment |
|---|---|
| One rectangular battery in the upper bay | Simplest wiring; the 37 × 25.5 mm allocation does not establish an improvement over the current 600 mAh pack. No larger fitting stocked pack has been verified. |
| Matched two-cell L arrangement | Uses the space beside the side-facing DAC; 800 mAh is a plausible target subject to the assembler's final outline and protection design. |
| One custom L-shaped cell | Potentially uses the corner space continuously; tooling, minimum order, capacity and finished outline require quotation. No purchasable exact part has been identified. |

## Port protection

The independently implemented T03 USB fix takes the real Seeed shell rim and offsets it by 0.15 mm. Result: 9.24 × 3.51 mm overall opening with the real curved profile. CAD checks verify the shell fits; this eliminates the old excess corner gaps. It does not establish a watertight interface.

For a sealed device, the intended construction needs both a seal between receptacle and enclosure and protection against leakage through the receptacle itself. Keep a removable silicone cover for USB and SD when unused. A flush cover would require a recess, a continuous sealing land and controlled compression, then plug-access and leak tests; no such cap has been represented as finished hardware in this study. The jack and other seams need equivalent consideration. A close metal opening alone cannot meet the requested no-dust/no-water objective.

If protection must continue while USB is exposed, use a connector designed with environmental sealing on a dedicated board. For example, [GCT USB4745](https://gct.co/news/usb4745) incorporates a sealing gasket and carries a connector-level IP68 specification. It is not a drop-in replacement for the XIAO connector, is not selected here, and does not give the assembled player an IP rating. Moving USB off the XIAO would require an electrical and mechanical redesign.

## Rebuild

From the repository root:

```sh
.venv/bin/python touchscreen_metal/studies/side_jack/build_study.py
node touchscreen_metal/verify_viewer.mjs
```

The build rejects component overlaps, reserve overlaps, full published DAC-envelope conflicts and parts outside the target exterior. These checks do not cover omitted mounting hardware, actual flex geometry, water protection, tolerance accumulation or a final battery assembly.

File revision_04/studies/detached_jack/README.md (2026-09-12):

# Detached-jack experiment: not selected

The active P04 design retains the complete Adafruit #6309 and its onboard jack.
On 2026-09-12 the user clarified that connector removal is useful only if it
reduces the complete device's thickness or footprint. The detached SJ-3523
experiment did neither with the retained battery and front UI, so it was removed
from the active CAD, BOM, preview and manufacturing package.

`rejected-experiment.zip` preserves the experimental source, parameters, reports
and socket references. This snapshot includes an interrupted update: some tests
and prose still describe removal of only one connector while the last parameters
remove both. It is historical evidence, not a validated release or a directly
rebuildable standalone project. Do not use it as assembly instructions.

Measured from the original Adafruit STEP, nominal DAC height was 6.372483 mm
intact, 6.37 mm with only PJ-332A removed, and 3.12 mm with PJ-332A and JSTPH2
removed. Both removals therefore recover about 3.25 mm locally. They do not
remove the 12.9 mm wheel/battery stack. The detached design also adds a separate
socket footprint, retaining cradle and leads.

The preceding implementation retained the intact board's 7.1 mm planning box
even after both sockets were removed. That box should not be used to evaluate
the modified board's actual local benefit. The independent battery constraint
still explains the zero whole-case gain. Any future experiment must model the
modified board with an explicit rework/insulation allowance and assess all
remaining stacks, including the remote socket and wire routing.

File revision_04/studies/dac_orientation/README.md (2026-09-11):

# mytunas: DAC orientation and compact packaging

> Historical study of the preceding 13.1 mm top-socket layout. The later 13.8 mm bottom-DAC layout was rejected. See the [current 12.9 mm arrangement](../../README.md), which keeps the battery entirely below the LCD and flips the upper DAC. Results and STEP files below remain historical references, excluded from the current manufacturing package, not current validation.

Research and CAD study, 2026-09-11. All selected modules, the original wheel and the 503040 battery are retained in the updated printable design. Moving the DAC or its jack opening is allowed. The top opening is a result of this comparison, not a fixed requirement.

## Implemented result

| | Previous compact P04 | Updated P04 |
|---|---:|---:|
| Length | 110 mm | 115 mm |
| Width | 70 mm | 60 mm |
| Thickness | 13.4 mm | 13.1 mm |
| Bounding-box volume | 103.18 cm3 | 90.39 cm3 |
| Battery-to-rear-skin allowance | 2.0 mm | 1.7 mm |

This saves **12.4% volume**, with a **10 mm narrower** grip and **0.3 mm less thickness**, at the cost of **5 mm more length**. It is not a large thickness breakthrough. Compared with the original 134 x 72 x 13.4 mm design, volume is down 30.08%.

The card module moves beside the wheel adapter, USB moves to the upper right of the battery, and the cell connector moves above USB. Screws move toward the ends to clear the original wheel and LCD in the narrower body. The LCD seat moves forward 0.3 mm, with 0.7 mm remaining behind the lens and a 0.2 mm bonding allowance. The DAC and rear shell follow that change. The full published DAC envelope remains intact.

The central wiring reserve now passes below the cell guides. It is 2.6 x 4.2 mm in cross-section, narrowing to 1.4 x 4.2 mm near the upper XIAO stop. Wire insulation diameter, bundle shape and bend transitions must be checked; empty-volume clearance is not completed harness routing. The XIAO stop uses a smaller upper contact land, which still needs insertion-force testing. The cell's remaining 1.7 mm is provisional space, not a supplier-qualified expansion allowance.

## What flipping actually changes

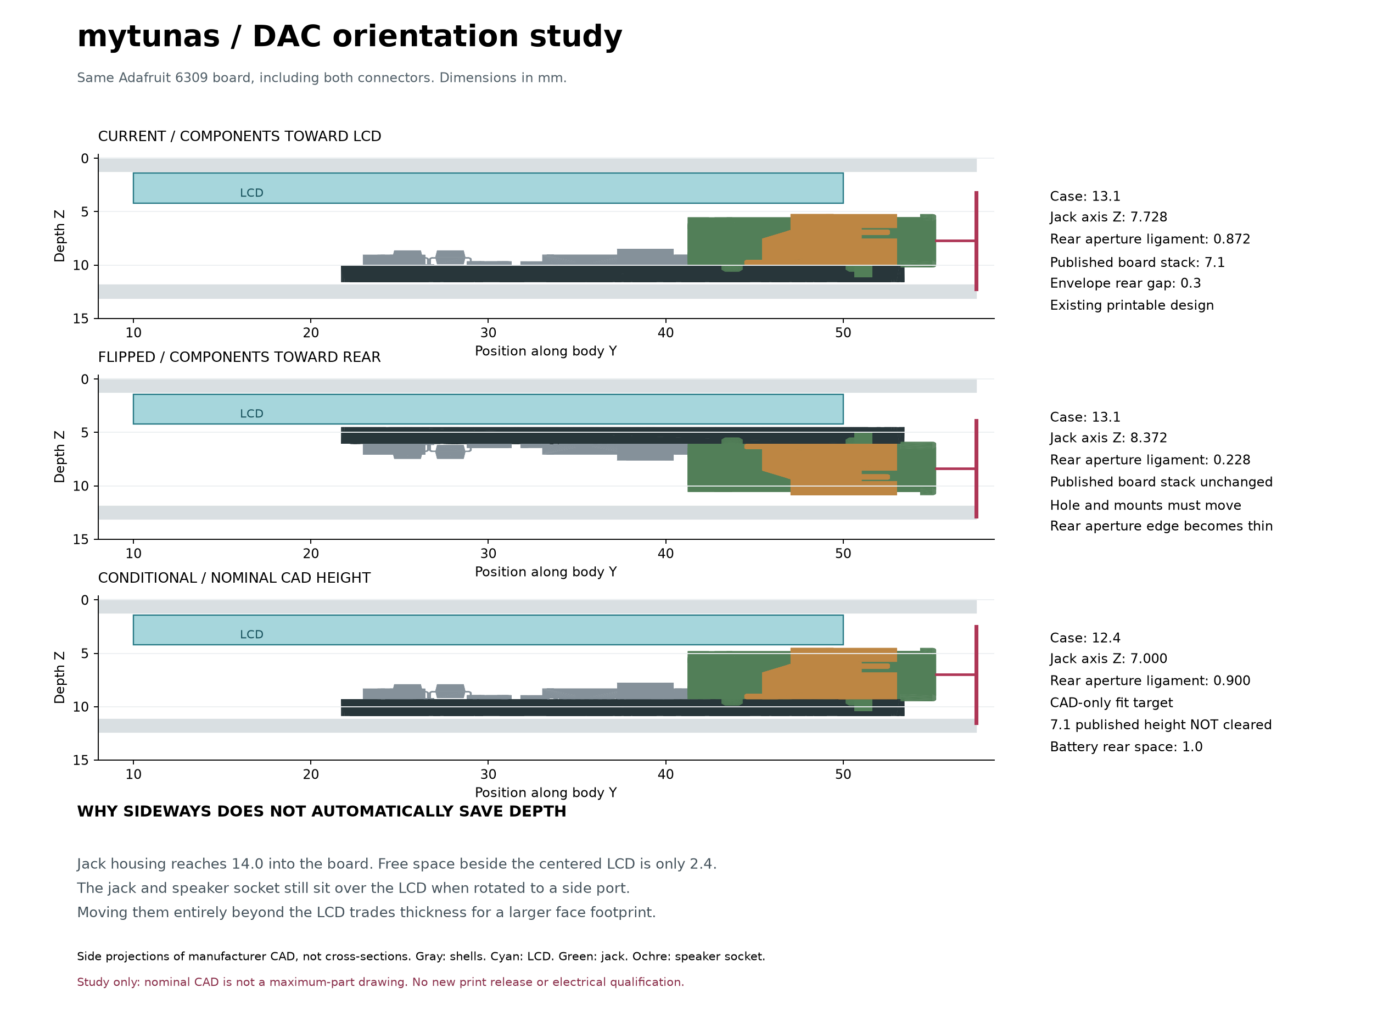
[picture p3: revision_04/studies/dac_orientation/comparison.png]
Manufacturer-CAD orientation comparison


The unscaled [Adafruit manufacturer model](https://learn.adafruit.com/adafruit-tlv320dac3100-i2s-dac/downloads) contains a 1.57 mm PCB, a jack reaching about 6.3725 mm above the board datum, and a speaker socket reaching 6.37 mm. The jack housing extends **14 mm along the PCB**. Its 3.5 mm bore is not its outside size. Adafruit publishes **33.7 x 25.4 x 7.1 mm** overall, so the physical planning allocation remains larger than the STEP. [Product dimensions](https://www.adafruit.com/product/6309)

The current depth stack is:

`LCD rear at 4.2 + 0.3 gap + 7.1 DAC + 0.3 gap + 1.2 rear skin = 13.1 mm`

A face flip preserves that stack. In the nominal STEP, it moves empty allocation from one side of the board to the other, which can look like recovered space in a render. It does not establish a smaller maximum component height.

Keeping the same envelope position while flipping moves the socket axis from **X +4.059 / Z 7.728** to **X -4.059 / Z 8.372 mm**. The hole must move with it. With the existing 9 mm plug-access opening, the rear ligament falls from **0.872 to 0.228 mm**. The study uses a provisional 0.8 mm ligament criterion; a rear-facing layout would need approximately 13.673 mm thickness under these assumptions, or a different plug/access design. This is a geometric screening criterion, not a proven material-strength rule.

The current and flipped STEP poses do not intersect the existing shells/components as solids. That alone does not prove fit: the flipped jack misses the existing aperture, and its back-side support/adhesive relationship changes. Neither alternative reference STEP is a printable release.

## Moving the board and jack

The script evaluates **380 rear-layer placements** across four socket directions and both board faces in the updated footprint. It uses separate manufacturer-part bounding boxes, the other component and routing envelopes, and corner-fastener exclusions. Top and left-facing layouts have the same best depth stack; changing to a side port alone does not reduce thickness. The right-side alternatives compete with USB, storage and their wiring.

This is a bounded placement screen. It does not prove that every possible three-dimensional arrangement has been exhausted, and it does not include tilted boards or arbitrary global component permutations. The printable repack separately changes the other boards, connector and fastener locations and passes the full existing CAD collision checks.

A second, **50-case study** moves the other components and front controls toward the bottom while moving the DAC toward the top. This creates a strip where the tall jack and speaker socket can sit beyond the LCD. Its conditional low-profile model adds the entire 0.7275 mm published/STEP discrepancy to each part's component-side height, retaining the 7.1 mm overall height. That is an explicit geometry hypothesis, not manufacturer confirmation of local maxima.

With the 1.7 mm battery reserve retained, this does not make the device thinner: the cell stack becomes the limit. Reducing that reserve to an unqualified 1.0 mm produces a **125 x 60 x 12.4 mm** candidate. It is 0.7 mm thinner but 10 mm longer and **2.9% larger in volume than the updated design**. Mounts, flex routes and shifted front openings would also need redesign. This is documented as a tradeoff, not released as a better enclosure.

There is a more attractive conditional target: **115 x 60 x 12.4 mm**, if the purchased DAC's finished height supports the 6.3725 mm nominal STEP plus the planned assembly allowances. This also leaves only 1.0 mm behind the nominal battery. Neither height is currently verified, so the printable design remains 13.1 mm.

## Lessons from Apple and open hardware

Apple specifies the seventh-generation iPod nano at **76.5 x 39.6 x 5.4 mm**. That demonstrates the result of a different integrated hardware platform; it is not a feasible target inferred for our 7.1 mm breakout and 5 mm cell. [Apple specifications](https://support.apple.com/en-us/112039)

iFixit's original teardown shows a small logic board, a battery behind the display, shaped flex interconnects, and soldered peripheral connections. The useful inference for mytunas is to co-design the enclosure, connector positions and interconnects, use exact component heights, and avoid overlapping the tallest structures. It does not justify removing insulation or reducing a printed wall to an aluminum-case thickness. [Original teardown](https://www.ifixit.com/Teardown/iPod+Nano+7th+Generation+Teardown/10826)

[Tangara](https://cooltech.zone/tangara/) is a particularly relevant open-hardware music player: its authors provide KiCad electronics, enclosure work and assembly documentation. Its architecture uses dedicated power management and an I2S DAC/headphone chain rather than treating a group of breakout boards as an electrically complete player. Our existing GPIO and power constraints still need bench resolution. [Tangara electronic design](https://cooltech.zone/tangara/docs/electronic-design/)

Tangara's authors also publish audio measurements and discuss how headphone load and gain affect distortion and noise. For mytunas, test the assembled player with its intended earphones and representative loads while storage, display and charging operate. A tighter layout is not evidence of better audio. [Tangara audio measurements](https://cooltech.zone/tangara/blog/2024-02-14-audio-quality/)

## Electrical and assembly constraints

- Keep the existing onboard jack connected directly to the headphone driver. Retain the unused speaker socket physically, leave it unconnected and disable the class-D speaker path. Use regulated 3.3 V headphone-only operation, common ground, I2C setup and reset. [Adafruit pinouts](https://learn.adafruit.com/adafruit-tlv320dac3100-i2s-dac/pinouts)
- Keep I2S clock/data routes short with adjacent ground returns. Preserve local supply bypassing and the codec's intended grounding. TI's chip-level guidance calls for close decoupling and deliberate analog/digital ground treatment; it is not a reason to cut the finished breakout's ground plane. [TI datasheet, layout section](https://www.ti.com/lit/ds/symlink/tlv320dac3100.pdf)
- Separate sensitive analog routing from digital and charging-current paths by placement. Do not introduce a ground-plane split across signal returns simply to label one area "analog." [Analog Devices grounding guidance](https://www.analog.com/en/resources/technical-articles/successful-pcb-grounding-with-mixedsignal-chips--follow-the-path-of-least-impedance.html)
- Retain the XIAO's onboard USB routing. Relocating the entire module does not require extending the USB differential pair; a redesigned PCB would need controlled impedance and a continuous reference plane. Core-chip layout recommendations are not automatically requirements to redesign the existing module. [Espressif layout guidance](https://docs.espressif.com/projects/esp-hardware-design-guidelines/en/latest/esp32s3/pcb-layout-design.html)
- Preserve bottom-contact wheel-flex orientation, latch access and a real bend radius. Radius depends on the actual flex thickness, layers and service motion. Fabricator examples cannot certify this unidentified original Apple flex. [JLCPCB flex capabilities](https://jlcpcb.com/capabilities/flex-pcb-capabilities)
- Verify regulator headroom, charge compatibility, peak current and temperature with all peripherals active. Battery discharge capability alone does not establish the XIAO rail budget. [Seeed battery and power documentation](https://wiki.seeedstudio.com/xiao_esp32s3_getting_started/)

## What enables the next reduction

Measure the assembled DAC across the jack, speaker socket, PCB underside and solder joints; identify the exact LCD board and connector; and obtain the finished battery dimensions and expansion/charge requirements. These distinguish a viable 12.4 mm target from a model-only fit. Also measure the selected earphone plug shoulder, flex construction and actual wire bundle.

A custom interconnect PCB or flex can preserve the selected modules while replacing bulky wiring, but its own thickness and connector lands consume space. Replacing breakout PCBs with a custom board carrying the same functional ICs would be a new electrical design, not the same complete modules: it needs a schematic, power and GPIO review, layout, fabrication and bench testing. No PCB was redesigned, no module was substituted or depopulated, and no untested audio or battery performance improvement is claimed here.

## Reproduce

From the repository root, run `.venv/bin/python revision_04/study_dac_orientation.py` after rebuilding the CAD. It produces [results.json](results.json), the [PDF comparison](comparison.pdf), and current/flipped assembly-coordinate STEP references. The report includes input hashes; packaging rejects stale study results. The separate main CAD/browser checks validate the printable design and interactive preview, not the conditional alternatives.

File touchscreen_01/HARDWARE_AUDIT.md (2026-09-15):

# Historical T01/T02 touchscreen hardware audit

This audit belongs to the superseded 2.01-inch touchscreen branch. It documents the older T01 concept and T02 bottom-jack prototype; it does not define the current [Model 02 touchscreen](../touchscreen_02/README.md), which has its own component evidence and release checklist.

The concept is promising, but the supplied wiring is **not ready to power**. The
15-pin assignments are user-supplied hypotheses. Searches for B006-01V0,
JL-M201B002-01 and Q1356-FC-A did not locate an exact manufacturer drawing or
pinout. A flex artwork code and pin count do not establish a common Jieli standard.
Audit date: 2026-09-12. No hardware was powered or firmware tested.

**Latest user specification supersedes the original touch-flex assumption:**
display FPC = **15-pin / 0.3 mm**; touch FPC = **6-pin / 0.5 mm**.
The earlier 15-pin touch table must not be applied to the six-pin flex. Its
six signal names are still power, ground, reset, interrupt, SCL and SDA as a
working hypothesis, but **their pin order is unknown**. No new numbered touch
pinout is inferred from connector size. The model now allocates a smaller
six-pin touch ZIF, separate from the fifteen-pin display ZIF.

## T02 mechanical and audio update

The latest user instruction places the battery above the intact Adafruit #6309, whose own jack faces the bottom wall. USB-C faces right and SD left. `geometry.py` derives the USB and jack axes from their manufacturer STEP coordinates, using the same rigid transforms as both CAD and viewer. Exterior openings are 9.4 × 3.7 mm (USB), 5 mm circular (jack), and 11.5 × 1.5 mm (SD). Blind internal reliefs preserve a 1 mm exterior lip. These are unsealed openings with no IP rating.

The supplied display stack is 0.25 mm cover glass + 0.70 mm touch sensor + 0.20 mm allocated adhesive + 2.15 mm LCD/backlight = 3.30 mm. The user confirmed **43 × 36 mm outer glass**, modeled landscape. Active borders and approximately 7 mm glass corner radius remain estimated from the photographs. The right-side ribbon exits are observed; their inward folds, lengths, stiffeners and bend limits are not measured.

The audio allowance is now an actual **Adafruit TLV320DAC3100 #6309**, with a published 33.7 × 25.4 × 7.1 mm envelope. The board requires I2C configuration and supports deriving its internal clock from I2S BCLK; it does not require a separate MCLK for this arrangement. Headphone operation can use its supported 3 V supply mode and its logic is 3.3 V. See [Adafruit's product specification](https://www.adafruit.com/product/6309). The ES9219/CS43131 discussion below audits the original proposal only; neither chip defines the current mechanical design.

The battery is the nominal protected **503040 / 40 × 30 × 5 mm / 600 mAh** from the chart and P04 selection. Finished pack dimensions and protection/lead protrusions still need verification; the earlier unselected 3.4 mm battery is no longer used. The custom interface board and SD construction are provisional design allocations, explicitly distinguished from the two manufacturer CAD models.

User follow-up identifies the donor as **T800 U2 / LJ737**, with an LJ736/JQ7011
sibling-board association. This strengthens the working SPI hypothesis; the
donor-board association remains user-provided rather than independently verified.
**0.3 mm is the user-specified display pitch, pending inspection.** Measure center-to-center
from the first to last of 15 contacts: 14 × 0.3 = 4.2 mm; 14 × 0.5 = 7.0 mm.
Do not measure just the entire flex width. Verify touch pitch independently and
confirm contact side, flex thickness, insertion depth and latch space before buying.

A concrete counterexample prevents treating this module class as a universal pinout:
manufacturer Lesson Smart Display lists [LSL0201I07-S-V1](https://jp.lessonsd.com/news/lsl0201i07-s-v1-2-01-inch-tft-lcd-240x296-spi-ips-cog-fpc-b-l-lens-jd9853-driver-ic.html),
a 2.01-inch 240×296 15-pin SPI panel using **JD9853**. Its table assigns pin 2
to RS/DC, pin 3 to CS, pin 10 to VCI and pin 12 to LEDA, unlike the proposed
B006 mapping. Its listed outline is 42 × 51.5 × 3.38 mm, also different from
this concept's assumed glass. This is **not an identification of your panel**,
and its pinout/dimensions must not be substituted for yours. It demonstrates
that panel-class similarity cannot settle the controller, wiring or mechanical fit.

## Findings

| Proposal | Evaluation and correction |
|---|---|
| Display CS grounded while sharing SCK/MOSI with SD | **Reject.** The selected display receives SD commands/data too. Give both devices independent CS signals and hold both high at startup. Select one at a time. |
| All 11 XIAO edge GPIOs allocated | Pin numbers match the standard S3 edge-pin map, but the grounded-CS trick makes the allocation invalid. Board variants/revisions expose different extra pads: inspect the actual board before relying on these. |
| Both panel rails and touch power at 3.3 V | **Unverified for these flexes.** Driver capability does not prove the module wiring or power limits. Establish VCI, IOVCC and touch I/O voltage independently; provide level translation if needed. |
| Ground pins 1–4 if copper exists | **Reject as an identification method.** Copper presence does not mean ground. Leave unidentified pins disconnected; use an authoritative drawing or trace them on the donor board. Shield continuity alone does not identify every signal. |
| Shared display/touch reset | Conditional on voltage, pulse timing, power sequencing and reset behavior of both actual ICs. Separate expander outputs avoid coupled resets. Do not let display initialization unexpectedly reset an already configured touch controller. |
| Poll touch at 50 Hz | Suitable for a first responsive UI if the controller supports polling. It does not provide touch wake from deep sleep when the CPU is no longer polling. Keep low-power wake unresolved until tested, or allocate a wake-capable direct GPIO using verified extra pads/a revised board. USB power cycling is only a bench recovery route. |
| 22 ohms from 3.3 V to LEDA | Cannot select without LED topology, forward voltage and rated current. At a hypothetical 3.2 V drop it gives (3.3−3.2)/22 ≈ **4.5 mA**, not a guaranteed operating current. Use a current-regulated driver matched to the actual backlight; account for voltage headroom. A USB supply limit does not independently limit every flex pin. |
| PCA9555 for brightness PWM | PCA9555 is a GPIO expander, without autonomous PWM. Use it for reset/enable; use a suitable LED driver with I2C brightness control, or free a native PWM GPIO and drive a transistor/current stage. |
| “FC” proves FocalTech; try 0x38 / 0x48 / 0x5D | The flex suffix does not establish an IC identity. 0x38 is a reasonable FT6x36 hypothesis after verified power, but alternative responding addresses do not make a device FT6x36-compatible. Identify the controller and read its ID using its documented protocol. |
| Try ST7789, then GC9307; fixed offset 24 | An initialization hypothesis, not identification. Confirm controller, interface straps, native RAM geometry and module-specific initialization. 240×296 in a hypothetical 240×320 RAM leaves 24 rows total; that does not tell us how the panel is aligned. Test all rotations and touch-coordinate transforms. |
| ES9219 or CS43131 uses just I2S plus I2C | These are chips, not interchangeable complete modules. A qualified board must include its required rails, analog support, clock source, reset and level translation. CS43131 has nominal 1.8 V logic/digital supplies and an XTI/MCLK clock path. ES9219 likewise has specific supply/clock requirements. Do not assume either accepts bare 3.3 V wiring or works with three I2S wires alone. |
| Thin LiPo on BAT pads | Need exact protected finished-pack dimensions, polarity, charge rating, continuous/peak current and the actual XIAO charger revision. Capacity/runtime cannot be inferred from “3.4 mm.” Total display/SD/audio/ESP32 rail and transient demand remain unmeasured. |

Espressif explicitly requires other SPI devices to be deselected while SD is
initialized into SPI mode. Its shared-bus notes also cover loading and startup
order: [Espressif shared SPI documentation](https://docs.espressif.com/projects/esp-idf/en/v5.0/esp32s3/api-reference/peripherals/sdspi_share.html).
The numerical edge-pin mapping is from [Seeed's pin reference](https://wiki.seeedstudio.com/xiao_esp32s3_pin_multiplexing/).

GPIO-expander behavior follows the [NXP PCA9555 datasheet](https://www.nxp.com/docs/en/data-sheet/PCA9555.pdf).
Audio requirements must be taken from the [CS43131 datasheet](https://statics.cirrus.com/pubs/proDatasheet/CS43131_DS1155F2.pdf)
or [ES9219 datasheet](https://www.esstech.com/wp-content/uploads/2026/03/ES9219-Datasheet-v1.3.pdf),
then reconciled with the selected module schematic.

## Corrected XIAO allocation for this concept

An I2C GPIO expander on the custom interface board moves slow reset/enable
signals off the MCU. It is required in this layout, rather than a later option.
This is a proposed **signal allocation**, not permission to connect the unknown flex pins.

| XIAO | GPIO | Signal |
|---|---:|---|
| D0 | 1 | Audio I2S data out → DAC data in |
| D1 | 2 | Display CS, active low, external pull-up to confirmed I/O rail |
| D2 | 3 | Display DC; ESP32-S3 strapping pin, avoid external loading that changes boot configuration |
| D3 | 4 | SD CS, active low, external pull-up |
| D4 | 5 | I2C SDA: touch, audio control, GPIO expander, optional LED driver |
| D5 | 6 | I2C SCL: same bus |
| D6 | 43 | I2S BCLK |
| D7 | 44 | I2S LRCLK / WS |
| D8 | 7 | Shared SPI SCK |
| D9 | 8 | SD MISO; display SDI does not connect here |
| D10 | 9 | Shared SPI MOSI |

| Expander output | Use |
|---|---|
| P0.0 | Display reset |
| P0.1 | Touch reset |
| P0.2 | Audio reset / enable, through level translation if required |
| P0.3 | Backlight driver enable |
| Others | Optional touch IRQ status input, mute or power controls; these do not automatically create an MCU wake interrupt |

PCA9555 powers up with pins configured as inputs. Give reset/enable signals
external resistors establishing the intended safe boot state. Initialize the
expander output latch before changing pin direction. Any expander output routed
to a lower-voltage peripheral needs a compatible interface. Confirm address
uniqueness, combined pull-up resistance and power-off backfeeding on I2C.
The allocated audio board must supply its own qualified clock if the chosen
DAC cannot derive the needed clock in this arrangement; otherwise GPIO budget changes.

## Firmware implications

1. Bring up known, verified rails; hold display and SD CS high, reset peripherals
   using the expander according to their datasheets.
2. Initialize one shared SPI bus and mount SD before sending display traffic.
3. With Arduino_GFX, use GPIO2 for display CS. Pass `GFX_NOT_DEFINED` as the
   display reset argument only **after** the application has reset it via I2C.
4. Select the identified controller and its validated offsets. The proposed
   `tft.invertDisplay(...)` variable name should be `gfx->invertDisplay(...)`
   when using the supplied pointer. Constructor and reset behavior can be checked
   in [Arduino_GFX's ST7789 implementation](https://github.com/moononournation/Arduino_GFX/blob/master/src/display/Arduino_ST7789.cpp).
5. Confirm both libraries use compatible shared-bus transactions and lock the
   bus across SD/display operations, including multiple tasks and any asynchronous
   DMA completion. Do not reinitialize the SPI peripheral underneath another client.
6. Poll the identified touch controller, reject invalid reads and calibrate touch
   orientation independently. Buffer audio so redraws do not starve decoding.

At RGB565, a full 240×296 frame is 142,080 bytes. A nominal 40 MHz SPI clock
gives only 35.2 full frames/s before protocol overhead and SD sharing; 60 complete
redraws/s would require 68.2 Mbit/s of pixel payload alone. Touch polling at 50 Hz
is compatible with a lower redraw rate. Use partial redraws and audio buffering;
no maximum stable SPI frequency is established for the salvaged panel.

## Evidence needed before powered bring-up or final fit

- Exact seller/donor/manufacturer drawing, pin-1 orientation and contact side;
  trace signals on the donor PCB if documentation is unavailable. No power from
  the guessed numbering alone.
- Full glass outline, black-border widths, corner radius, total panel thickness,
  both tail exit positions/lengths, stiffeners, connector thickness and latch travel.
- Verify the purchased Adafruit revision against the retained manufacturer CAD; measure the headphone plug shoulder and mounting-hole clearance.
- Finished protected battery measurements and electrical ratings, including the
  protection end and leads; 600 mAh is the nominal selected-pack rating, not a measured result.
- A measured charging/current budget, sample fit, flex-fold trial, touch wake
  test and sustained audio + SD + redraw test.

No power switch and no external antenna are modeled, consistent with the original
player direction. This concept does not establish wireless performance, touch wake
from deep sleep or restart from a completely unpowered state.

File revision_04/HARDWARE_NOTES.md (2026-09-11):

# P04 hardware evidence and connection notes

## Battery change

The user explicitly selected a protected **503040, 3.7 V, 600 mAh**, advertised as **5 × 30 × 40 mm**. The supplied seller listing states a **1–1.5 A working/discharge-current range** and **up to 3 A maximum discharge**. This supersedes the approximately 2000 mAh target and the AKYGA candidate in P02. The earlier 400 mAh examples were alternatives in the supplied background, not the selected battery.

The compact repack turns the same battery to 30 mm across × 40 mm along × 5 mm deep, centered at X −11.2, Y −3 mm. Those are the supplied listing dimensions; no exact manufacturer datasheet, finished-pack maxima or protection-board geometry has been provided. The connector is likely a PH 2.0 plug, but polarity is not standardized across vendors and must be checked on the actual pack before connection. The CAD reserves an 8 × 10 × 5 mm connector pocket at X 18, Y 26, Z 5.1 mm, above the XIAO and connected to the upper routing bridge. Its adequacy still depends on the actual plug and wire exit; rendered leads and flex are illustrative routes, not measured harnesses. The reduced case leaves 1.7 mm behind the nominal cell, down from 2.0 mm. That is a design allowance, not a certified expansion requirement.

At the same nominal voltage, 600/2000 = **30%** of P02's capacity and energy. Nominal stored energy changes from 7.4 Wh to 2.22 Wh. With identical average battery current, an ideal capacity-based runtime estimate also falls to 30%; actual runtime depends on operating current, converter losses and cutoff. This is not a playback-time measurement.

The advertised 5 mm body is only 0.5 mm below the prior candidate's published 5.5 mm maximum. These are different specification bases; most of the layout benefit is the smaller footprint. The seller's 1–1.5 A working range is approximately 1.7–2.5C for 600 mAh, and the stated 3 A maximum is 5C. Treat those as seller listing claims until measured. Protection and discharge-current claims do not establish charging requirements.

Seeed supports a qualified rechargeable 3.7 V lithium battery on the XIAO battery pads. Confirm that this exact pack permits the board's charge voltage/current and connect it to BAT+/BAT− with checked polarity. The 3V3 pin is not the battery charging connection. [Seeed battery documentation](https://wiki.seeedstudio.com/xiao_esp32s3_getting_started/#battery-usage)

The XIAO's 5 V pin does not provide 5 V on battery power. A breakout needing a 5 V VIN therefore needs a proven supply arrangement; identifying its DAC chip alone does not establish the module's battery compatibility. [Seeed battery documentation](https://wiki.seeedstudio.com/xiao_esp32s3_getting_started/#battery-usage)

## Combined DAC and headphone amplifier

P04 replaces the PCM5102A and its separate amplifier reservation with one **Adafruit TLV320DAC3100, product 6309**. Its onboard 3.5 mm stereo headphone output accepts passive earphones; Adafruit specifically documents direct 16-ohm headphone operation. The published board size is **33.7 × 25.4 × 7.1 mm**. [Product and dimensions](https://www.adafruit.com/product/6309)

The board supports regulated 3.3 V headphone-only operation and 3.3 V logic. Use common ground. The unused speaker connection remains empty, and firmware must disable the speaker amplifier. Configure its PLL from BCK so that MCK can remain unconnected. I²C and a low-to-high hardware reset are required; replacing only the old board's three I2S wires will not start playback. [Official pinouts](https://learn.adafruit.com/adafruit-tlv320dac3100-i2s-dac/pinouts)

| Audio board connection | Proposed XIAO connection |
|---|---|
| VIN / GND | Regulated 3V3 / GND |
| SDA | D4, GPIO5 |
| SCL | D5, GPIO6 |
| BCK | GPIO39, underside MTCK pad |
| WSEL | GPIO40, underside MTDO pad |
| DIN | GPIO41, underside MTDI pad |
| RST | GPIO42, underside MTMS pad |
| MCK | Unconnected; configure BCK-derived PLL |
| 3.5 mm socket | User's passive earphones |

This is a **proposed allocation**, not tested firmware. GPIO39–42 are additional solder pads, not four spare normal side-header pins; do not also enable their JTAG functions. The D11/D12 names alias GPIO42/41 and do not provide extra GPIO. [Seeed pin map](https://wiki.seeedstudio.com/xiao_esp32s3_getting_started/)

That allocation consumes six control/audio GPIO, leaving nine of the 15 candidate accessible GPIO for the rest of the player. A possible budget uses six for shared LCD/SD SPI (clock, MOSI, MISO, two chip selects and LCD D/C), plus three for wheel clock/data/button. It leaves no spare GPIO for independent LCD reset, PWM backlight or wheel command data. Shared codec/LCD reset is only a candidate if the exact LCD supports compatible active-low 3.3 V reset; coordinated startup would be required. Wheel event mode may avoid the host-command line, but must be verified on the monochrome wheel. Thus pin count is feasible for a constrained configuration, not proof that every peripheral feature or sleep mode works. Retain this explicit integration check before final wiring.

Use the [Adafruit Arduino setup and library](https://learn.adafruit.com/adafruit-tlv320dac3100-i2s-dac/arduino) as the initialization reference. Firmware work must match PLL/dividers and sample format to the XIAO I2S stream, enable stereo DAC/headphone paths, begin muted at low gain, and coordinate mute/reset/power-down with playback and sleep. The repository currently contains mechanical design scripts, not player firmware; this revision does not claim an implemented audio driver.

Power is planned from the XIAO's regulated 3V3 rail, not its USB-only 5 V output. Measure the combined controller/display/SD/wheel/audio peak current, rail droop and temperature on battery power. Do not infer a sufficient whole-system power budget from voltage compatibility. The advertised battery's 3 A claim does not establish regulator capacity. No extra supply module is selected or silently added.

The current 12.9 mm shell places the battery entirely below the LCD, behind the wheel, and the flipped DAC at the upper left. Components face the rear, with the headphone socket at the top. The full 7.1 mm published DAC height, 0.3 mm depth gaps and original 1.7 mm battery rear allowance are retained. The gain over 13.1 mm comes from a local 1.0 mm LCD seat floor and a wheel seat lowered 0.2 mm, not from shrinking the boards or compressing the battery. Both face orientations fit at this location; the selected one is Y-flipped relative to the original 13.1 mm layout. Manufacturer CAD puts the headphone axis at X-13.359, Z8.1725, with its mouth 0.05 mm inside the top face. The 5 mm circular aperture surrounds the 4.6 mm barrel. Three rear locating posts use actual mounting holes and leave 0.2 mm for insulating adhesive on their PCB lands. Fit the real board, solder joints, adhesives and plug before accepting the mounts. The LCD pocket's stiffness and near-flush wheel/button motion need physical tests. No port or seam is sealed. See [current arrangement and fit limits](README.md) and [vendor evidence](vendor/README.md). Direct solder wiring, controlled return paths and strain relief remain required; reserves are not a routed or electrically tested harness.

## Clickwheel adapter and pin numbering

The adapter's purpose is now confirmed: it breaks out the monochrome 4th-generation clickwheel flex. The following table records the user's supplied pin order; wheel GPIO numbers remain unassigned pending the complete pin budget and sample protocol checks above.

| Flex pin | User-supplied signal | Connection intent / status |
|---|---|---|
| 1 | VBat | Proposed regulated 3.3 V wheel supply; not the raw battery connection |
| 2 | SCK | Wheel-generated, tri-state clock to MCU input; external pull-up to 3.3 V |
| 3 | CFG1 | Proposed event-only setup: tie high to 3.3 V; low enables continuous packets and commands |
| 4 | BTN1 | Normally low button pulse to a wake-capable MCU input; verify wake configuration |
| 5 | Unknown | Leave unconnected pending identification |
| 6 | MOSI | Open-drain wheel-to-MCU data; external pull-up to 3.3 V |
| 7 | MISO | MCU-to-wheel commands in CFG1=0 mode; unused in proposed event-only setup |
| 8 | GND | Common ground |

An original reverse-engineering project supports this order and wheel-master interpretation, but its measurements used a **4th-generation Photo/color wheel**, not a verified sample of this monochrome replacement. Treat it as supporting evidence, not a tested pinout for every replacement flex. It reports pull-ups on **both SCK and MOSI**, and shows that CFG1=0 selects a mode with host commands while CFG1=1 sends events. Thus CFG1 is a configuration input that may intentionally be low; it is not a second ground terminal. A four-wire demonstration does not establish full sleep/wake behavior or justify leaving configuration floating. Confirm flex contact numbering and adapter continuity before applying power. [Original clickwheel research](https://github.com/Gigahawk/clickwheel_reverse_eng)

The latest user-supplied description contradicts itself in its final CFG1 wiring instruction. Use **high for event-only**, not the suggested ground connection. This is the provisional mode for the three-input GPIO budget (SCK, MOSI, BTN1); dynamic CFG1 and MISO commands would need a revised allocation. Start bench testing with external 10 kΩ pull-ups on clock and data as a design candidate, then check rise times on the actual harness.

The supplied protocol details are a firmware bring-up reference: 32-bit packets at roughly 55 kHz, idle-high clock, falling-edge sampling and LSB-first decoding. The research treats sampling edge and bit order as assumptions; validate decoded packets before fixing the receiver implementation. This is a wheel-clocked custom interface without ordinary SPI chip-select framing, so an ordinary MCU SPI-master driver is unsuitable.

The user's event format is `0x35`, button mask, position, touch flag. Position runs from `0x00` through `0xBE` in steps of two; ignore it unless touch is asserted (`0x80`). Their command-mode notes record `95 02 00 C0` for sleep and `1D 01 00 C0` with reply `75 04 02 00` during wake initialization. These are reference observations, not implemented or sample-tested firmware.

BTN1 is a wake candidate only while the wheel has power and the controller's selected sleep mode can detect that GPIO. A fully unpowered XIAO cannot restart from a GPIO pulse alone; that would require an always-powered enable/latch circuit, which this design does not include. Keep the planned software power control as a sleep/wake function until current and wake behavior are measured.
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

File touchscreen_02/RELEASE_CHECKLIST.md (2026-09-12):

# M02-03 production-release gates

Status: **mechanical fit prototype, not production-ready**. The selected exterior is preserved, and modeled assembly checks are automated. The following are concrete unresolved engineering items, not tests inferred to have passed from a render.
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

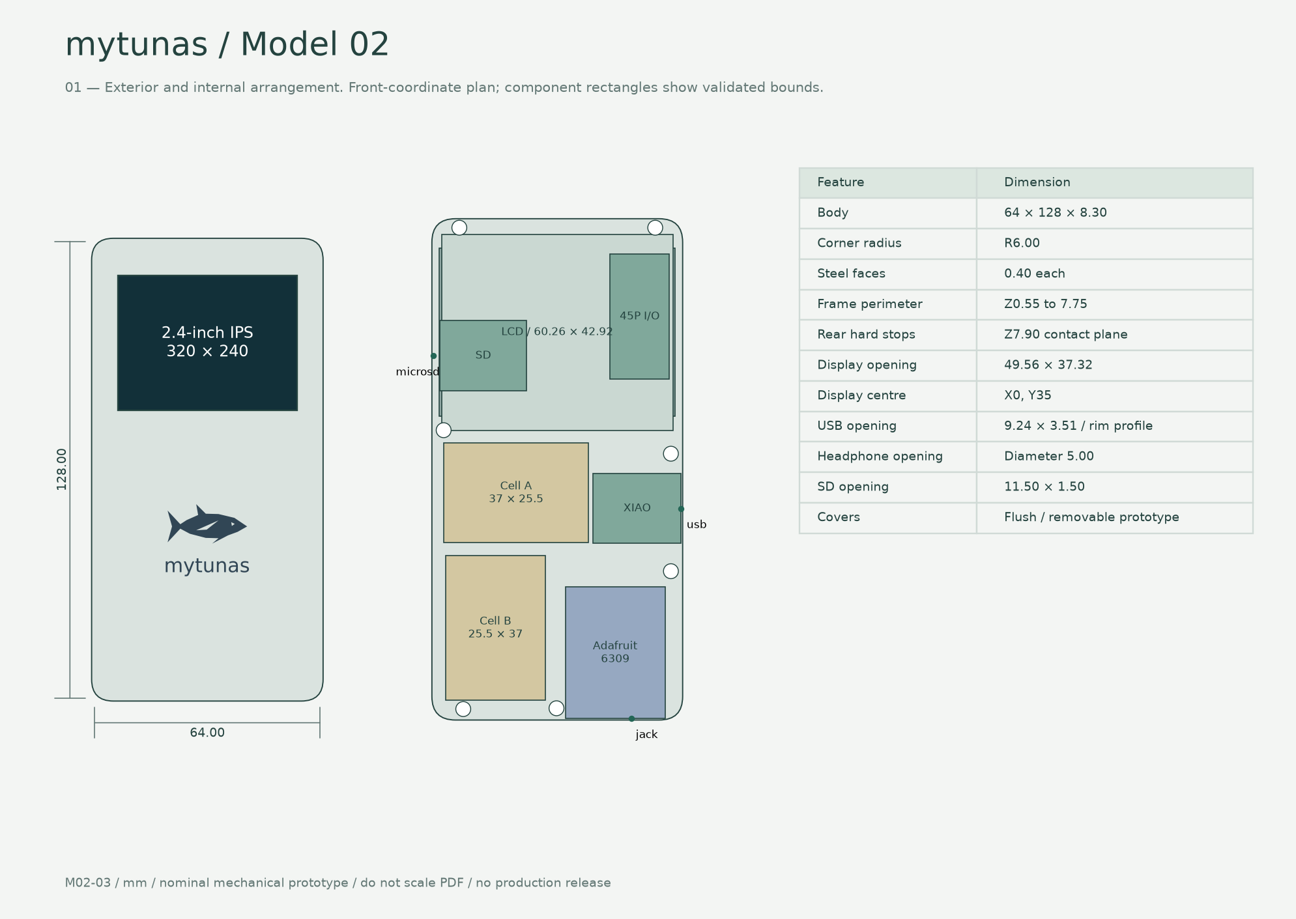
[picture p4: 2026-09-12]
touchscreen_02/design_overview.png

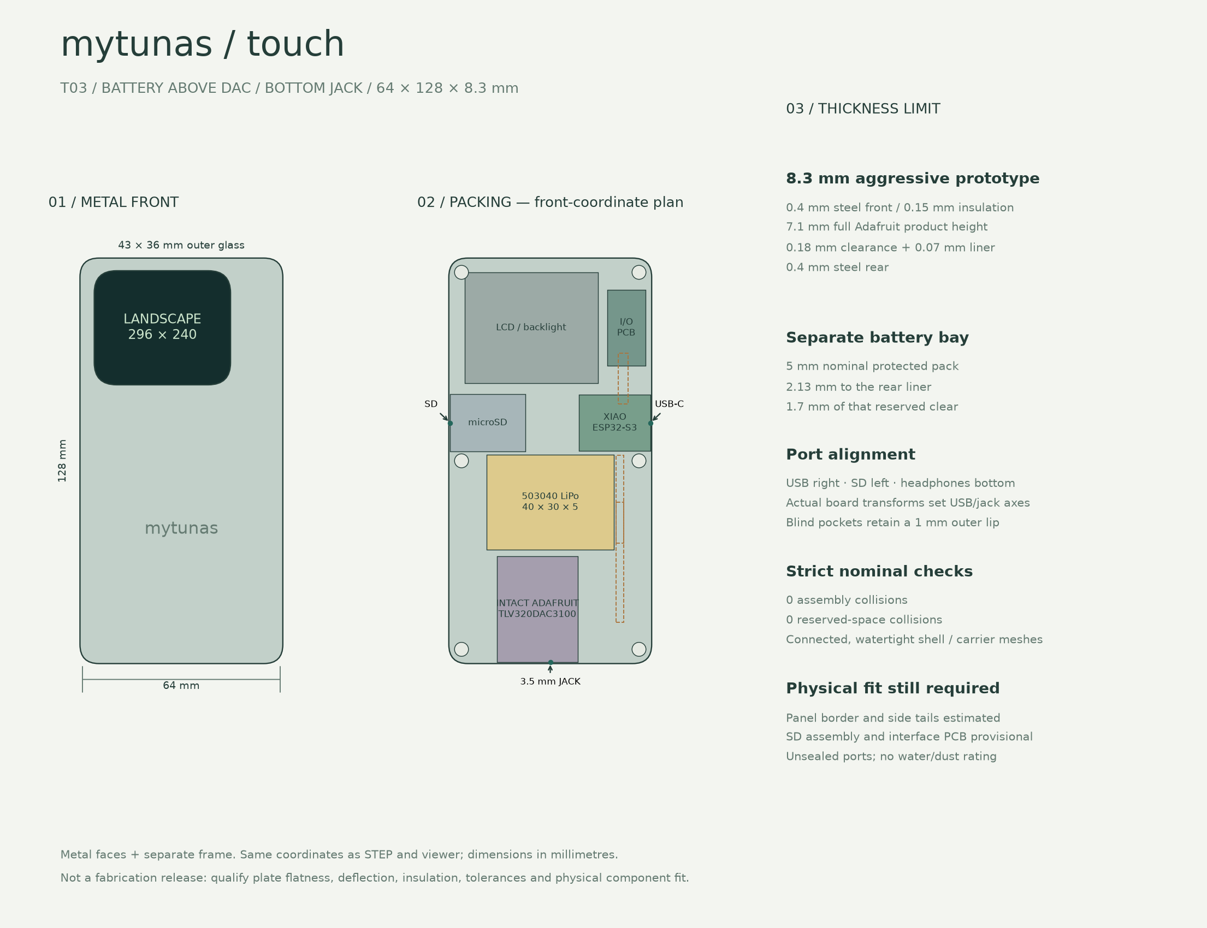
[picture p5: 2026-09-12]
touchscreen_metal/design_overview.png

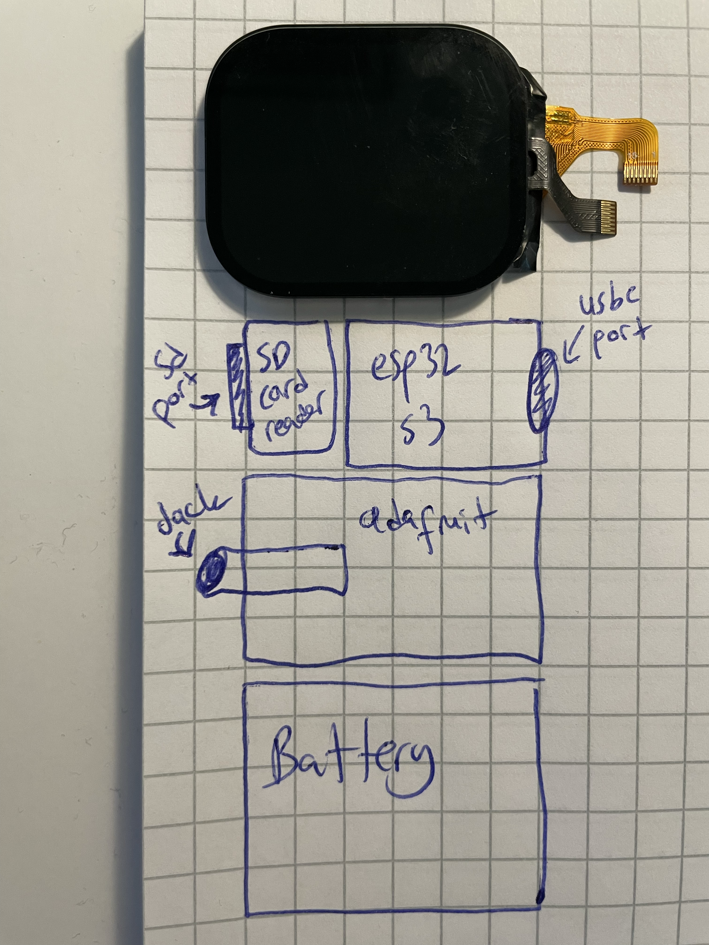
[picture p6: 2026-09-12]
touchscreen_01/scan/newtouchscreendesign.png

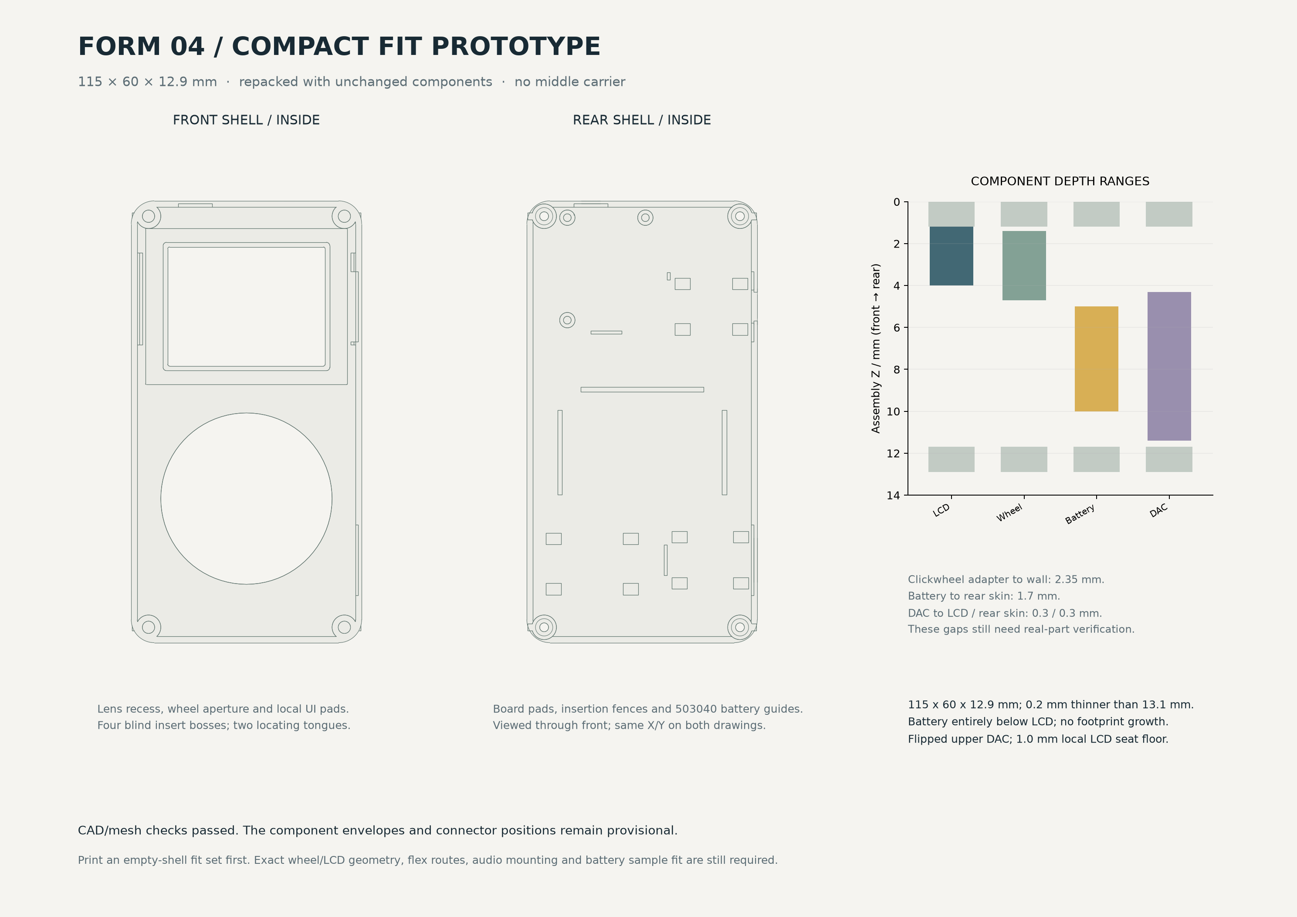
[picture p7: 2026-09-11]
revision_04/design_overview.png

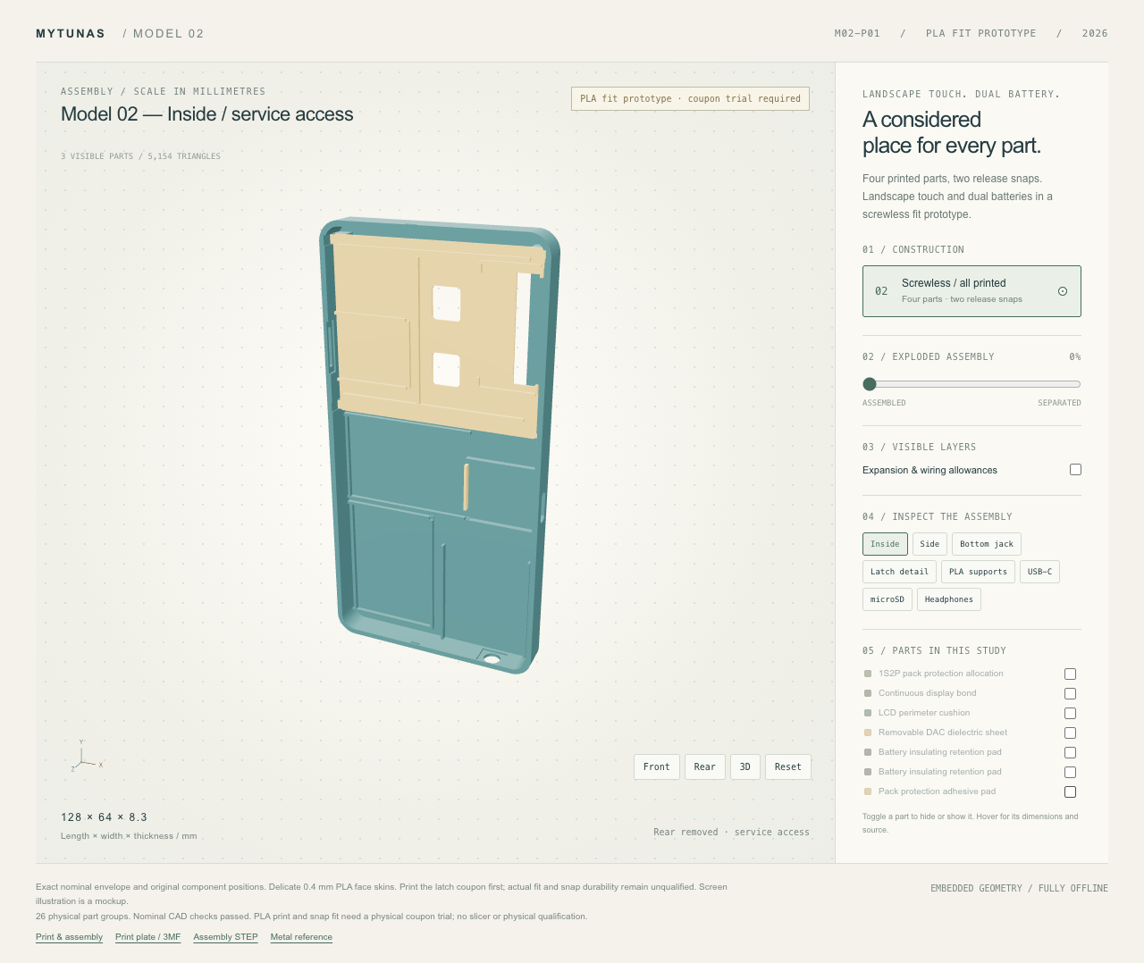
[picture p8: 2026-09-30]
touchscreen_02/pla_fit/preview_supports.png

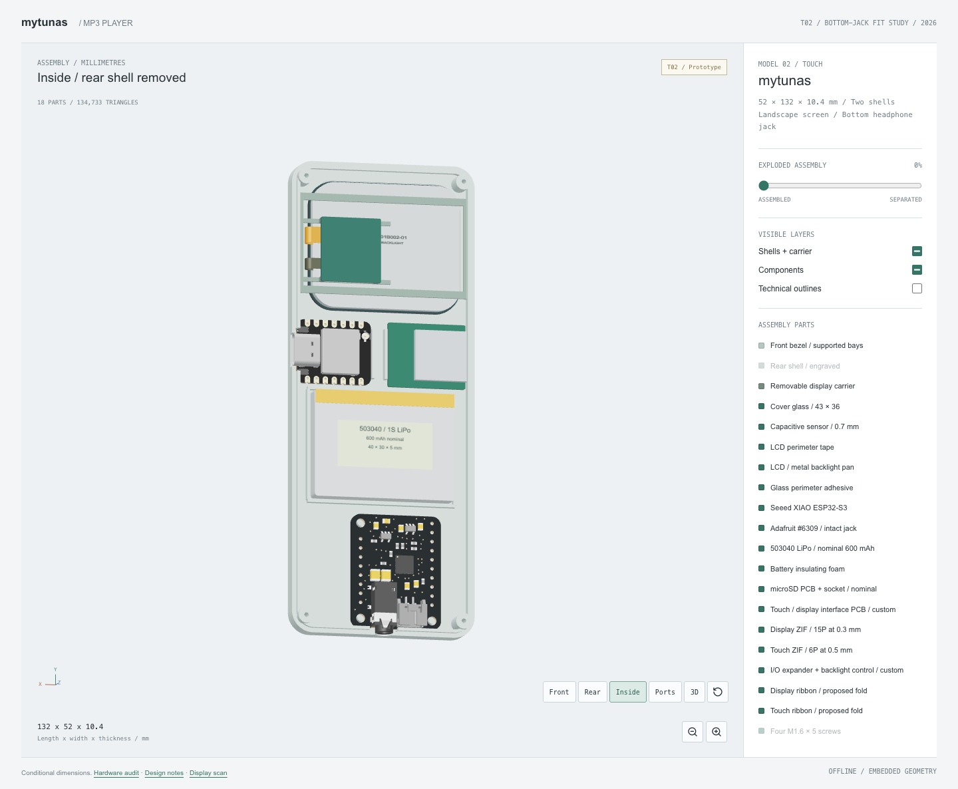
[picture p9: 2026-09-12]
touchscreen_01/preview_inside.png

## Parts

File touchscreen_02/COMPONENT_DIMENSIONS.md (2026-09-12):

# Dimensional evidence and limits

Every physical part appears in `measurements.csv` with its CAD bounds and position. `BOM.csv` identifies its source. No bought component is scaled to fit.

| Assembly | Definition used | Status |
|---|---|---|
| Adafruit #6309 | Unscaled STEP: 33.537 × 25.400 × 6.372 mm; full published 33.7 × 25.4 × 7.1 mm retained as space requirement | Manufacturer CAD; measure finished board including solder |
| XIAO ESP32-S3 | Unscaled manufacturer STEP including USB shell, shield and castellations | Exact CAD bounds in CSV; verify purchased board revision |
| Startek KD024QVFMA020-C003A | Listing: 42.92 × 60.26 × 3.75 mm; touch 42.62 × 59.96 × 1.25 mm | Nominal supplier dimensions; controlled drawing, tolerances and actual tails pending |
| Two cell sections | Each finished envelope 37 × 25.5 × 5.2 mm; one rotated in plane | DTP502535 pack maximum; matched combined 1S2P assembly not selected |
| PEM MSIB-M1.6-300 | OD 2.5 ±0.1 mm; length 3 ±0.1 mm; pilot 2.15 ±0.05 mm; minimum hole depth 3.77 mm | Published envelope, no invented knurls/threads; PA12 installation unqualified |
| PEM MSIB-M1.4-150 | OD 2.5 ±0.1 mm; length 1.5 ±0.1 mm; pilot 2.15 ±0.05 mm; minimum hole depth 2.27 mm | Published envelope; PA12 installation unqualified |
| SD board/socket | PCB 22 × 18 × 0.8 mm; socket allocation 15.7 × 14.2 × 1.8 mm | Custom board and socket not selected/routed |
| Display interface | PCB 15 × 32 × 0.8 mm and 45-pin 0.5 mm ZIF allocation | Not a completed PCB or confirmed connector drawing |
| Protection / harness | Pack protection allocation and routing spaces | Not a completed circuit, harness or service connector |
| Screws | M1.6 × 5 countersunk; M1.4 × 3 pan/countersunk as labelled | Nominal; supplier head/drive drawings still required |
| Faces, carrier, saddle, DAC columns | Custom dimensioned CAD | Intended manufactured geometry, not existing commercial parts |
| Polymer seats, pads, dielectric layers and covers | Installed dimensional shapes | Material, free-state shape, compression and retention remain prototype definitions |

Sources: [Adafruit CAD](https://github.com/adafruit/Adafruit_CAD_Parts/tree/main/6309%20TLV320DAC3100%20I2S%20DAC), [Seeed resources](https://wiki.seeedstudio.com/xiao_esp32s3_getting_started/#resources), [Startek listing](https://www.startek-lcd.com/product/474-KD024QVFMA020-C003A-2.4-inch-240x320-ST7789V-IPS-LCD-module-with-build-in-capacitive-touch-panel.html), [DTP drawing](https://www.digikey.com/htmldatasheets/production/2065026/0/0/1/prt-13851.pdf), [PEM M1.6](https://www.pemnet.com/products/product-finder/msib-m1-6-300/), [PEM M1.4](https://www.pemnet.com/products/product-finder/msib-m1-4-150/).

Insert cylinders represent installed bounding geometry. The separate BEFORE_HEAT_INSERTS frame has smaller installation pilots; printing the assembled cavities would not establish retention. Rear DAC columns are custom turned metal parts with insulating shoulders. Electronics and off-the-shelf standoffs have not been resized to create them.

The original front bluefin mark is vector artwork in `assets/branding.json`; CAD and engraving SVGs use identical contours. Rear text identifies the prototype revision, with no invented regulatory approvals, serial numbers, capacities or Apple trademarks.

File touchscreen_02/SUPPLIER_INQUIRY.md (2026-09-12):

# Draft only — not sent

Subject: Sample availability and complete drawing — KD024QVFMA020-C003A

Hello,

We are evaluating KD024QVFMA020-C003A for a compact ESP32-S3 music player. Please quote two complete LCD-plus-capacitive-touch samples and confirm:

1. Current stock of this exact suffix, unit price, minimum order and lead time. Please identify any proposed substitute separately.
2. Maximum assembled dimensions and tolerances, including glass, adhesive, controller-on-flex, folded tails and stiffeners. Your product page lists 42.92 × 60.26 × 3.75 mm; does this include the full touch assembly?
3. Dimensioned mechanical drawing and STEP file, if available, plus permitted flex bend radius and connector mating/locking clearance.
4. Exact LCD and touch FPC pinouts, connector pitch/contact side, supply and I/O voltages, and backlight voltage/current requirements.
5. Confirm 4-wire SPI pixel transfer with an independent chip-select signal and FT6336G I²C touch. Please provide the module-specific initialization sequence and touch documentation.
6. Sample shipping options and expected production availability.

The panel must fit landscape in a 64 mm wide enclosure with approximately 60.8 mm between side walls, so maximum dimensions and tolerances are essential.

Thank you.

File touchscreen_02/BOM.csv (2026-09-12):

part_id | quantity | description | type | definition | qualification
case_insert_1 | 1 | PEM MSIB-M1.6-300 / case_insert_1 | fastener | PEM published 2.5 mm OD envelope; installed polymer displacement modeled; knurl/thread omitted | Nominal prototype; physical qualification required
case_insert_2 | 1 | PEM MSIB-M1.6-300 / case_insert_2 | fastener | PEM published 2.5 mm OD envelope; installed polymer displacement modeled; knurl/thread omitted | Nominal prototype; physical qualification required
case_insert_3 | 1 | PEM MSIB-M1.6-300 / case_insert_3 | fastener | PEM published 2.5 mm OD envelope; installed polymer displacement modeled; knurl/thread omitted | Nominal prototype; physical qualification required
case_insert_4 | 1 | PEM MSIB-M1.6-300 / case_insert_4 | fastener | PEM published 2.5 mm OD envelope; installed polymer displacement modeled; knurl/thread omitted | Nominal prototype; physical qualification required
case_insert_5 | 1 | PEM MSIB-M1.6-300 / case_insert_5 | fastener | PEM published 2.5 mm OD envelope; installed polymer displacement modeled; knurl/thread omitted | Nominal prototype; physical qualification required
case_insert_6 | 1 | PEM MSIB-M1.6-300 / case_insert_6 | fastener | PEM published 2.5 mm OD envelope; installed polymer displacement modeled; knurl/thread omitted | Nominal prototype; physical qualification required
case_insert_7 | 1 | PEM MSIB-M1.6-300 / case_insert_7 | fastener | PEM published 2.5 mm OD envelope; installed polymer displacement modeled; knurl/thread omitted | Nominal prototype; physical qualification required
carrier_insert_1 | 1 | PEM MSIB-M1.4-150 / carrier_insert_1 | fastener | PEM published 2.5 mm OD envelope; installed polymer displacement modeled; knurl/thread omitted | Nominal prototype; physical qualification required
carrier_insert_2 | 1 | PEM MSIB-M1.4-150 / carrier_insert_2 | fastener | PEM published 2.5 mm OD envelope; installed polymer displacement modeled; knurl/thread omitted | Nominal prototype; physical qualification required
carrier_insert_3 | 1 | PEM MSIB-M1.4-150 / carrier_insert_3 | fastener | PEM published 2.5 mm OD envelope; installed polymer displacement modeled; knurl/thread omitted | Nominal prototype; physical qualification required
carrier_insert_4 | 1 | PEM MSIB-M1.4-150 / carrier_insert_4 | fastener | PEM published 2.5 mm OD envelope; installed polymer displacement modeled; knurl/thread omitted | Nominal prototype; physical qualification required
xiao_clamp_insert_1 | 1 | PEM MSIB-M1.4-150 / xiao_clamp_insert_1 | fastener | PEM published 2.5 mm OD envelope; installed polymer displacement modeled; knurl/thread omitted | Nominal prototype; physical qualification required
xiao_clamp_insert_2 | 1 | PEM MSIB-M1.4-150 / xiao_clamp_insert_2 | fastener | PEM published 2.5 mm OD envelope; installed polymer displacement modeled; knurl/thread omitted | Nominal prototype; physical qualification required
midframe | 1 | PA12 frame / metal insert seats and guides | structure | Designed nominal geometry | Nominal prototype; physical qualification required
front_bezel | 1 | Front satin polished steel / laser engraved / 0.40 mm | structure | Designed nominal geometry | Nominal prototype; physical qualification required
rear_shell | 1 | Rear satin polished steel / laser engraved / 0.40 mm | structure | Designed nominal geometry | Nominal prototype; physical qualification required
front_bond | 1 | front bond / 0.15 mm | seal | Designed nominal geometry | Nominal prototype; physical qualification required
rear_gasket | 1 | rear gasket / 0.15 mm | seal | Designed nominal geometry | Nominal prototype; physical qualification required
touch_glass | 1 | Startek capacitive glass / nominal 1.25 mm | component | Startek listing; sample drawing required | Nominal prototype; physical qualification required
lcd | 1 | Startek LCD + backlight / nominal 2.50 mm | component | Startek outline; layer split pending supplier drawing | Nominal prototype; physical qualification required
display_adhesive | 1 | Continuous display bond / 0.15 mm | seal | Designed nominal geometry | Nominal prototype; physical qualification required
display_carrier | 1 | Welded stainless carrier / cross ribs and service windows | structure | Designed nominal geometry | Nominal prototype; physical qualification required
display_cushion | 1 | LCD perimeter cushion / 0.05 mm | seal | Designed nominal geometry | Nominal prototype; physical qualification required
audio | 1 | Adafruit 6309 / original bottom jack | component | Unscaled manufacturer STEP | Manufacturer CAD; sample fit required
xiao | 1 | Seeed XIAO ESP32-S3 / USB right | component | Unscaled manufacturer STEP | Manufacturer CAD; sample fit required
audio_insulator | 1 | Removable DAC dielectric sheet / 0.15 mm | seal | Designed nominal geometry | Nominal prototype; physical qualification required
xiao_insulator | 1 | Removable XIAO dielectric seat / 0.35 mm | seal | Designed nominal geometry | Nominal prototype; physical qualification required
xiao_saddle | 1 | Removable stainless XIAO saddle / two screws | structure | Designed nominal geometry | Nominal prototype; physical qualification required
xiao_saddle_pad | 1 | XIAO shield cushion / installed 0.30 mm | seal | Actual shield top Z4.00; compression and allowable shield load require test | Nominal prototype; physical qualification required
xiao_clamp_screw_1 | 1 | M1.4 × 3 XIAO saddle screw | fastener | Designed nominal geometry | Nominal prototype; physical qualification required
xiao_clamp_screw_2 | 1 | M1.4 × 3 XIAO saddle screw | fastener | Designed nominal geometry | Nominal prototype; physical qualification required
xiao_insertion_stop | 1 | Removable XIAO insertion stop | support | Designed nominal geometry | Nominal prototype; physical qualification required
xiao_stop_adhesive | 1 | XIAO stop bonding pad | seal | Designed nominal geometry | Nominal prototype; physical qualification required
dac_seat_1 | 1 | Insulating DAC shoulder and locating pin | support | Custom POM; nominal 0.10 mm radial pin-to-hole clearance | Nominal prototype; physical qualification required
dac_retainer_1 | 1 | Threaded stainless DAC column 1 | support | Custom turned stainless M1.4 column; thread not tessellated | Nominal prototype; physical qualification required
dac_rear_screw_1 | 1 | M1.4 × 3 countersunk DAC column screw | fastener | Designed nominal geometry | Nominal prototype; physical qualification required
dac_seat_2 | 1 | Insulating DAC shoulder and locating pin | support | Custom POM; nominal 0.10 mm radial pin-to-hole clearance | Nominal prototype; physical qualification required
dac_retainer_2 | 1 | Threaded stainless DAC column 2 | support | Custom turned stainless M1.4 column; thread not tessellated | Nominal prototype; physical qualification required
dac_rear_screw_2 | 1 | M1.4 × 3 countersunk DAC column screw | fastener | Designed nominal geometry | Nominal prototype; physical qualification required
dac_seat_3 | 1 | Insulating DAC shoulder and locating pin | support | Custom POM; nominal 0.10 mm radial pin-to-hole clearance | Nominal prototype; physical qualification required
dac_retainer_3 | 1 | Threaded stainless DAC column 3 | support | Custom turned stainless M1.4 column; thread not tessellated | Nominal prototype; physical qualification required
dac_rear_screw_3 | 1 | M1.4 × 3 countersunk DAC column screw | fastener | Designed nominal geometry | Nominal prototype; physical qualification required
rear_liner | 1 | Rear dielectric liner / 0.07 mm | seal | Designed nominal geometry | Nominal prototype; physical qualification required
cell_A_envelope | 1 | Battery A / finished pack allocation | component | DTP502535 max pack dimensions; combined pack unselected | Nominal prototype; physical qualification required
cell_A_envelope_adhesive | 1 | Battery insulating retention pad / 0.30 mm | seal | Designed nominal geometry | Nominal prototype; physical qualification required
cell_B_envelope | 1 | Battery B / finished pack allocation | component | DTP502535 max pack dimensions; combined pack unselected | Nominal prototype; physical qualification required
cell_B_envelope_adhesive | 1 | Battery insulating retention pad / 0.30 mm | seal | Designed nominal geometry | Nominal prototype; physical qualification required
microsd_pcb | 1 | microSD adapter PCB / nominal 22 × 18 | component | Designed nominal geometry | Nominal prototype; physical qualification required
microsd_socket | 1 | microSD socket / conservative envelope | component | Designed nominal geometry | Nominal prototype; physical qualification required
microsd_card | 1 | microSD card | component | Designed nominal geometry | Nominal prototype; physical qualification required
sd_mount_pad | 1 | SD insulating adhesive / 0.30 mm | seal | Designed nominal geometry | Nominal prototype; physical qualification required
sd_stop_19_5 | 1 | SD edge stop | support | Designed nominal geometry | Nominal prototype; physical qualification required
sd_stop_19_5_bond | 1 | SD stop bond / 0.05 mm | seal | Designed nominal geometry | Nominal prototype; physical qualification required
sd_stop_38_5 | 1 | SD edge stop | support | Designed nominal geometry | Nominal prototype; physical qualification required
sd_stop_38_5_bond | 1 | SD stop bond / 0.05 mm | seal | Designed nominal geometry | Nominal prototype; physical qualification required
sd_insertion_stop | 1 | SD insertion load stop | support | Designed nominal geometry | Nominal prototype; physical qualification required
sd_insertion_stop_bond | 1 | SD insertion stop bond / 0.05 mm | seal | Designed nominal geometry | Nominal prototype; physical qualification required
interface_pcb | 1 | 45P display / touch interface PCB allocation | component | Designed nominal geometry | Nominal prototype; physical qualification required
interface_pad_24 | 1 | Interface insulating mounting land | seal | Designed nominal geometry | Nominal prototype; physical qualification required
interface_pad_54 | 1 | Interface insulating mounting land | seal | Designed nominal geometry | Nominal prototype; physical qualification required
display_zif | 1 | LCD ZIF / 45P 0.5 mm allocation | component | Designed nominal geometry | Nominal prototype; physical qualification required
touch_zif | 1 | Touch ZIF / supplier pinout pending | component | Designed nominal geometry | Nominal prototype; physical qualification required
interface_control | 1 | I/O + backlight control allocation | component | Designed nominal geometry | Nominal prototype; physical qualification required
pack_protection | 1 | 1S2P pack protection allocation | component | Designed nominal geometry | Nominal prototype; physical qualification required
pack_protection_pad | 1 | Pack protection adhesive pad | seal | Designed nominal geometry | Nominal prototype; physical qualification required
case_screw_1 | 1 | M1.6 × 5 case screw 1 | fastener | Designed nominal geometry | Nominal prototype; physical qualification required
case_screw_2 | 1 | M1.6 × 5 case screw 2 | fastener | Designed nominal geometry | Nominal prototype; physical qualification required
case_screw_3 | 1 | M1.6 × 5 case screw 3 | fastener | Designed nominal geometry | Nominal prototype; physical qualification required
case_screw_4 | 1 | M1.6 × 5 case screw 4 | fastener | Designed nominal geometry | Nominal prototype; physical qualification required
case_screw_5 | 1 | M1.6 × 5 case screw 5 | fastener | Designed nominal geometry | Nominal prototype; physical qualification required
case_screw_6 | 1 | M1.6 × 5 case screw 6 | fastener | Designed nominal geometry | Nominal prototype; physical qualification required
case_screw_7 | 1 | M1.6 × 5 case screw 7 | fastener | Designed nominal geometry | Nominal prototype; physical qualification required
carrier_screw_1 | 1 | M1.4 × 3 retainer screw 1 | fastener | Designed nominal geometry | Nominal prototype; physical qualification required
carrier_screw_2 | 1 | M1.4 × 3 retainer screw 2 | fastener | Designed nominal geometry | Nominal prototype; physical qualification required
carrier_screw_3 | 1 | M1.4 × 3 retainer screw 3 | fastener | Designed nominal geometry | Nominal prototype; physical qualification required
carrier_screw_4 | 1 | M1.4 × 3 retainer screw 4 | fastener | Designed nominal geometry | Nominal prototype; physical qualification required
usb_cover | 1 | Flush USB-C silicone cover / prototype | cover | Designed nominal geometry | Nominal prototype; physical qualification required
sd_cover | 1 | Flush SD silicone cover / prototype | cover | Designed nominal geometry | Nominal prototype; physical qualification required
jack_cover | 1 | Flush jack silicone cover / prototype | cover | Designed nominal geometry | Nominal prototype; physical qualification required

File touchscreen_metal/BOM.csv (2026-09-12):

Item | Qty | Part | Specification | Status
1 | 1 | Front face | 0.4 mm stainless steel / DXF and STEP | Aggressive prototype; flatness and deflection unverified
2 | 1 | Rear face | 0.4 mm stainless steel / countersunk screw seats | Aggressive prototype; qualify countersink process
3 | 1 | Internal frame | PA12 candidate / 7.2 mm nominal height | Polymer fit prototype
4 | 1 | Display retainer | 0.4 mm metal / removable | Profile and STEP; edge finishing required
5 | 1 | Salvaged touchscreen | 43 x 36 outer glass / 3.3 mm stack | User dimensions; tails and border unverified
6 | 1 | Seeed XIAO ESP32-S3 | Headerless / actual vendor STEP | USB faces right
7 | 1 | Adafruit TLV320DAC3100 #6309 | Intact board / full 7.1 mm height allowance | Original jack faces bottom
8 | 1 | Protected 503040 LiPo | 40 x 30 x 5 / nominal 600 mAh | Existing selection; measure finished pack
9 | 1 | microSD PCB and cage | 22 x 18 PCB allowance | Representative module; select actual socket
10 | 1 | Custom interface PCB | 12 x 24 x 0.8 | Placement allocation; layout not completed
11 | 1 | Display ZIF | 15P / 0.3 mm pitch / left entry | Select exact part and contact side
12 | 1 | Touch ZIF | 6P / 0.5 mm pitch / left entry | Select exact part and contact side
13 | 1 | Expander and backlight support | Allocated on interface PCB | Schematic and layout outstanding
14 | 1 | DAC dielectric pad | 0.15 mm total allowance | Must include complete insulation and board underside features
15 | 2 | XIAO and SD dielectric pads | 0.35 mm total allowance each | Representative pad geometry
16 | 1 | Rear liner | 0.07 mm thin dielectric film | 3M 5413 thickness class; application qualification required
17 | 1 | Battery insulating pad | 38 x 28 x 0.3 | Nominal
18 | 1 | Front perimeter bond | 0.15 mm | Material and process unselected
19 | 1 | Rear perimeter gasket | 0.15 mm compressed target | Material unselected; no IP claim
20 | 3 | Nonconductive DAC retaining spacers | Actual board hole positions | Clamp/bonding trial required
21 | 6 | Case screws | M1.6 x 5 countersunk nominal | Select actual head drawing and qualify pilot
22 | 2 | Display retainer screws | M1 small screws / nominal 3 mm under head | Select actual screw and qualify pilot
23 | 1 | Wiring and strain relief | Reserved side lanes | Loom not yet detailed

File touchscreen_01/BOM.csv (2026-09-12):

Item | Qty | Part | Nominal specification | Source/status
1 | 1 | T800 U2 salvaged landscape touchscreen | 43 x 36 outer glass / 3.3 mm stack with tape | User measurement and photos; outline and flex bends provisional
2 | 1 | Seeed XIAO ESP32-S3 | Headerless / USB right | Unscaled Seeed manufacturer STEP
3 | 1 | Adafruit TLV320DAC3100 #6309 | 25.4 x 33.7 x 7.1 allowance / onboard jack down | Unscaled Adafruit STEP; full published height retained
4 | 1 | Protected 503040 LiPo | 40 x 30 x 5 / nominal 600 mAh | User chart and P04 selection; measure finished protected pack
5 | 1 | microSD PCB and low-profile socket | 22 x 18 PCB / card exits left | Representative construction; exact module not selected
6 | 1 | Custom interface PCB | 17 x 18 x 0.8 | Design allocation; PCB routing not completed
7 | 1 | Display ZIF | 15 contacts / 0.3 mm pitch / underside mounted | Housing and contact side require selection
8 | 1 | Touch ZIF | 6 contacts / 0.5 mm pitch / underside mounted | Housing and contact side require selection
9 | 1 | GPIO expander and backlight support parts | Allocated on custom PCB | Schematic and power budget still required
10 | 1 | Front bezel | T02_bottom_jack / 1.6 mm wall | Fit prototype STL and STEP
11 | 1 | Rear shell | T02_bottom_jack / 1.2 mm skin with 0.25 engraving | Fit prototype STL and STEP
12 | 1 | Removable display carrier | 0.6 mm web with board lands | Fit prototype; qualify material and printing
13 | 4 | Case screws | M1.6 x 5 / root-diameter CAD | Test polymer pilot fit; no insert assumed
14 | 1 | Screen perimeter adhesive | 0.2 mm nominal | Die-cut to verified glass border
15 | 1 | Battery insulating foam | 38 x 28 x 0.6 | Nominal placement pad
16 | 1 | Wiring and insulation | Reserved side and upper service lanes | Loom and connector details not yet designed

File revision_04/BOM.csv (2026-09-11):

item | quantity | part | status
Audio board | 1 | Adafruit TLV320DAC3100 product 6309 | Selected combined DAC/headphone amplifier with onboard 3.5mm jack; direct solder wires; no headers
Controller | 1 | Seeed XIAO ESP32-S3 | Retained assumed envelope; GPIO and power budget require bench validation
Display | 1 | 2 inch ST7789 IPS 240x320 | Retained 52x40x2.8mm landscape assumption; exact module unverified
Clickwheel | 1 | Original iPod 4th-generation monochrome wheel | Identity user confirmed; dimensions and flex geometry provisional
Wheel adapter | 1 | 8-pin FPC breakout | Your Cee listing: obverse 0.5mm pitch; reverse 1.0mm pitch; PCB thickness 1.6mm; locking bottom-contact socket included per user; clickwheel pitch confirmed 0.5mm so use 8P 0.5mm side; 26.1x19.1x4.2mm assembled planning envelope
Storage | 1 | microSD module | Retained 22x18x4mm envelope
Battery | 1 | Protected 503040 3.7V 600mAh | User selected advertised 5x30x40mm; finished dimensions and charge rating unverified
Front shell | 1 | P04 front_bezel.stl | 115x60mm thin fit prototype; 1.0mm local LCD seat floor; 0.2mm lower wheel seat; use matching rear shell
Rear shell | 1 | P04 rear_shell.stl | 115x60x12.9mm top-jack fit prototype; DAC mounting-hole posts; centered mytunas logo and name engraved 0.3mm into exterior
Fit coupon | 1 | insert_and_clearance_fit_coupon.stl | Print before selecting inserts
Lens | 1 | Clear sheet 43x33x0.6mm | Reference DXF; confirm actual display offsets
Inserts | 4 | M2 heat-set inserts | Select for provisional 3.2mm diameter by 3.2mm deep pilots using coupon
Screws | 4 | M2x7 | Heads must fit 4.5mm diameter recesses
Wiring and insulation | as needed | Low-profile soldered harness and insulating adhesive | 0.2mm nominal pad allowance; qualify actual materials and strain relief

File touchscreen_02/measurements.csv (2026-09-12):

part | label | width_mm | length_mm | height_mm | xmin_mm | ymin_mm | zmin_mm | source
case_insert_1 | PEM MSIB-M1.6-300 / case_insert_1 | 2.50056 | 2.50084 | 3.00112 | -26.25 | 60.44958 | 4.49944 | PEM published 2.5 mm OD envelope; installed polymer displacement modeled; knurl/thread omitted
case_insert_2 | PEM MSIB-M1.6-300 / case_insert_2 | 2.50056 | 2.50084 | 3.00112 | 23.75 | 60.44958 | 4.49944 | PEM published 2.5 mm OD envelope; installed polymer displacement modeled; knurl/thread omitted
case_insert_3 | PEM MSIB-M1.6-300 / case_insert_3 | 2.50056 | 2.50084 | 3.00112 | -30.25 | 8.74958 | 4.49944 | PEM published 2.5 mm OD envelope; installed polymer displacement modeled; knurl/thread omitted
case_insert_4 | PEM MSIB-M1.6-300 / case_insert_4 | 2.50056 | 2.50084 | 3.00112 | 27.75 | 2.74958 | 4.49944 | PEM published 2.5 mm OD envelope; installed polymer displacement modeled; knurl/thread omitted
case_insert_5 | PEM MSIB-M1.6-300 / case_insert_5 | 2.50056 | 2.50084 | 3.00112 | 27.75 | -27.25042 | 4.49944 | PEM published 2.5 mm OD envelope; installed polymer displacement modeled; knurl/thread omitted
case_insert_6 | PEM MSIB-M1.6-300 / case_insert_6 | 2.50056 | 2.50084 | 3.00112 | -1.45 | -62.25042 | 4.49944 | PEM published 2.5 mm OD envelope; installed polymer displacement modeled; knurl/thread omitted
case_insert_7 | PEM MSIB-M1.6-300 / case_insert_7 | 2.50056 | 2.50084 | 3.00112 | -25.25 | -62.45042 | 4.49944 | PEM published 2.5 mm OD envelope; installed polymer displacement modeled; knurl/thread omitted
carrier_insert_1 | PEM MSIB-M1.4-150 / carrier_insert_1 | 2.50056 | 2.50084 | 1.50112 | -26.25 | 10.04958 | 2.84944 | PEM published 2.5 mm OD envelope; installed polymer displacement modeled; knurl/thread omitted
carrier_insert_2 | PEM MSIB-M1.4-150 / carrier_insert_2 | 2.50056 | 2.50084 | 1.50112 | 23.75 | 10.04958 | 2.84944 | PEM published 2.5 mm OD envelope; installed polymer displacement modeled; knurl/thread omitted
carrier_insert_3 | PEM MSIB-M1.4-150 / carrier_insert_3 | 2.50056 | 2.50084 | 1.50112 | -24.25 | 57.44958 | 2.84944 | PEM published 2.5 mm OD envelope; installed polymer displacement modeled; knurl/thread omitted
carrier_insert_4 | PEM MSIB-M1.4-150 / carrier_insert_4 | 2.50056 | 2.50084 | 1.50112 | 21.75 | 57.44958 | 2.84944 | PEM published 2.5 mm OD envelope; installed polymer displacement modeled; knurl/thread omitted
xiao_clamp_insert_1 | PEM MSIB-M1.4-150 / xiao_clamp_insert_1 | 2.50056 | 2.50084 | 1.50112 | 20.75 | -22.95042 | 2.79944 | PEM published 2.5 mm OD envelope; installed polymer displacement modeled; knurl/thread omitted
xiao_clamp_insert_2 | PEM MSIB-M1.4-150 / xiao_clamp_insert_2 | 2.50056 | 2.50084 | 1.50112 | 20.75 | 0.44958 | 2.79944 | PEM published 2.5 mm OD envelope; installed polymer displacement modeled; knurl/thread omitted
midframe | PA12 frame / metal insert seats and guides | 64.00508 | 128.00508 | 7.35369 | -32.00254 | -64.00254 | 0.54712 | Designed nominal geometry
front_bezel | Front satin polished steel / laser engraved / 0.40 mm | 64.00508 | 128.00508 | 0.40508 | -32.00254 | -64.00254 | -0.00254 | Designed nominal geometry
rear_shell | Rear satin polished steel / laser engraved / 0.40 mm | 64.00508 | 128.00508 | 0.4093 | -32.00254 | -64.00254 | 7.89535 | Designed nominal geometry
front_bond | front bond / 0.15 mm | 64.00506 | 128.00506 | 0.15506 | -32.00253 | -64.00253 | 0.39747 | Designed nominal geometry
rear_gasket | rear gasket / 0.15 mm | 64.00506 | 128.00506 | 0.15506 | -32.00253 | -64.00253 | 7.74747 | Designed nominal geometry
touch_glass | Startek capacitive glass / nominal 1.25 mm | 59.96 | 42.62 | 1.25 | -29.98 | 13.69 | 0.55 | Startek listing; sample drawing required
lcd | Startek LCD + backlight / nominal 2.50 mm | 60.26 | 42.92 | 2.5 | -30.13 | 13.54 | 1.8 | Startek outline; layer split pending supplier drawing
display_adhesive | Continuous display bond / 0.15 mm | 59.6603 | 42.3203 | 0.1503 | -29.83015 | 13.83985 | 0.39985 | Designed nominal geometry
display_carrier | Welded stainless carrier / cross ribs and service windows | 59.00135 | 50.00191 | 1.45098 | -29.50093 | 9.99907 | 4.34902 | Designed nominal geometry
display_cushion | LCD perimeter cushion / 0.05 mm | 58.00034 | 41.00034 | 0.05034 | -29.00017 | 14.49983 | 4.29983 | Designed nominal geometry
audio | Adafruit 6309 / original bottom jack | 25.4 | 33.53701 | 6.37248 | 2.1 | -63.6 | 0.55 | Unscaled manufacturer STEP
xiao | Seeed XIAO ESP32-S3 / USB right | 22.48198 | 17.78 | 4.46 | 9.11802 | -18.89 | 0.75 | Unscaled manufacturer STEP
audio_insulator | Removable DAC dielectric sheet / 0.15 mm | 25.4 | 31.75 | 0.15 | 2.1 | -61.81299 | 0.4 | Designed nominal geometry
xiao_insulator | Removable XIAO dielectric seat / 0.35 mm | 20.9 | 17.7 | 0.35 | 9.14611 | -18.85 | 0.4 | Designed nominal geometry
xiao_saddle | Removable stainless XIAO saddle / two screws | 3.60129 | 27.00161 | 0.40161 | 20.19935 | -23.50081 | 4.29919 | Designed nominal geometry
xiao_saddle_pad | XIAO shield cushion / installed 0.30 mm | 2.0 | 8.0 | 0.3 | 21.0 | -14.0 | 4.0 | Actual shield top Z4.00; compression and allowable shield load require test
xiao_clamp_screw_1 | M1.4 × 3 XIAO saddle screw | 2.20049 | 2.20074 | 3.60072 | 20.9 | -22.80037 | 1.69978 | Designed nominal geometry
xiao_clamp_screw_2 | M1.4 × 3 XIAO saddle screw | 2.20049 | 2.20074 | 3.60072 | 20.9 | 0.59963 | 1.69978 | Designed nominal geometry
xiao_insertion_stop | Removable XIAO insertion stop | 0.5 | 15.4 | 1.7 | 8.4 | -16.45 | 0.55 | Designed nominal geometry
xiao_stop_adhesive | XIAO stop bonding pad | 0.5 | 15.4 | 0.15 | 8.4 | -16.45 | 0.4 | Designed nominal geometry
dac_seat_1 | Insulating DAC shoulder and locating pin | 3.70083 | 3.70124 | 1.72134 | 23.11 | -34.45361 | 0.54949 | Custom POM; nominal 0.10 mm radial pin-to-hole clearance
dac_retainer_1 | Threaded stainless DAC column 1 | 3.40076 | 3.40114 | 5.63408 | 23.26 | -34.30356 | 2.26924 | Custom turned stainless M1.4 column; thread not tessellated
dac_rear_screw_1 | M1.4 × 3 countersunk DAC column screw | 2.81048 | 2.8108 | 3.00579 | 23.55507 | -34.00839 | 5.29976 | Designed nominal geometry
dac_seat_2 | Insulating DAC shoulder and locating pin | 3.70083 | 3.70124 | 1.72134 | 2.79 | -61.12361 | 0.54949 | Custom POM; nominal 0.10 mm radial pin-to-hole clearance
dac_retainer_2 | Threaded stainless DAC column 2 | 3.40076 | 3.40114 | 5.63408 | 2.94 | -60.97356 | 2.26924 | Custom turned stainless M1.4 column; thread not tessellated
dac_rear_screw_2 | M1.4 × 3 countersunk DAC column screw | 2.81048 | 2.8108 | 3.00579 | 3.23507 | -60.67839 | 5.29976 | Designed nominal geometry
dac_seat_3 | Insulating DAC shoulder and locating pin | 3.70083 | 3.70124 | 1.72134 | 23.11 | -61.12361 | 0.54949 | Custom POM; nominal 0.10 mm radial pin-to-hole clearance
dac_retainer_3 | Threaded stainless DAC column 3 | 3.40076 | 3.40114 | 5.63408 | 23.26 | -60.97356 | 2.26924 | Custom turned stainless M1.4 column; thread not tessellated
dac_rear_screw_3 | M1.4 × 3 countersunk DAC column screw | 2.81048 | 2.8108 | 3.00579 | 23.55507 | -60.67839 | 5.29976 | Designed nominal geometry
rear_liner | Rear dielectric liner / 0.07 mm | 60.40356 | 124.40267 | 0.07356 | -30.20178 | -62.20178 | 7.82822 | Designed nominal geometry
cell_A_envelope | Battery A / finished pack allocation | 37.00068 | 25.50068 | 5.20068 | -29.00034 | -18.75034 | 0.69966 | DTP502535 max pack dimensions; combined pack unselected
cell_A_envelope_adhesive | Battery insulating retention pad / 0.30 mm | 35.00051 | 23.50051 | 0.30051 | -28.00025 | -17.75025 | 0.39975 | Designed nominal geometry
cell_B_envelope | Battery B / finished pack allocation | 25.50068 | 37.00068 | 5.20068 | -28.50034 | -59.00034 | 0.69966 | DTP502535 max pack dimensions; combined pack unselected
cell_B_envelope_adhesive | Battery insulating retention pad / 0.30 mm | 23.50051 | 35.00051 | 0.30051 | -27.50025 | -58.00025 | 0.39975 | Designed nominal geometry
microsd_pcb | microSD adapter PCB / nominal 22 × 18 | 22.00042 | 18.00042 | 0.80042 | -29.90021 | 19.99979 | 4.84979 | Designed nominal geometry
microsd_socket | microSD socket / conservative envelope | 15.7 | 14.2 | 1.8 | -30.85 | 21.9 | 5.65 | Designed nominal geometry
microsd_card | microSD card | 15.0 | 11.0 | 1.0 | -31.6 | 23.5 | 5.9 | Designed nominal geometry
sd_mount_pad | SD insulating adhesive / 0.30 mm | 20.0 | 16.0 | 0.3 | -28.9 | 21.0 | 4.55 | Designed nominal geometry
sd_stop_19_5 | SD edge stop | 20.0 | 0.5 | 0.95 | -28.0 | 19.25 | 4.6 | Designed nominal geometry
sd_stop_19_5_bond | SD stop bond / 0.05 mm | 20.0 | 0.5 | 0.05 | -28.0 | 19.25 | 4.55 | Designed nominal geometry
sd_stop_38_5 | SD edge stop | 20.0 | 0.5 | 0.95 | -28.0 | 38.25 | 4.6 | Designed nominal geometry
sd_stop_38_5_bond | SD stop bond / 0.05 mm | 20.0 | 0.5 | 0.05 | -28.0 | 38.25 | 4.55 | Designed nominal geometry
sd_insertion_stop | SD insertion load stop | 0.6 | 17.0 | 0.95 | -7.6 | 20.5 | 4.6 | Designed nominal geometry
sd_insertion_stop_bond | SD insertion stop bond / 0.05 mm | 0.6 | 17.0 | 0.05 | -7.6 | 20.5 | 4.55 | Designed nominal geometry
interface_pcb | 45P display / touch interface PCB allocation | 15.00034 | 32.00034 | 0.80034 | 13.49983 | 22.99983 | 4.84983 | Designed nominal geometry
interface_pad_24 | Interface insulating mounting land | 7.0 | 1.4 | 0.3 | 14.5 | 23.3 | 4.55 | Designed nominal geometry
interface_pad_54 | Interface insulating mounting land | 7.0 | 1.4 | 0.3 | 14.5 | 53.3 | 4.55 | Designed nominal geometry
display_zif | LCD ZIF / 45P 0.5 mm allocation | 5.0 | 26.5 | 1.1 | 22.3 | 25.75 | 5.65 | Designed nominal geometry
touch_zif | Touch ZIF / supplier pinout pending | 3.5 | 5.0 | 1.1 | 15.25 | 24.5 | 5.65 | Designed nominal geometry
interface_control | I/O + backlight control allocation | 6.0 | 12.0 | 1.1 | 14.0 | 35.0 | 5.65 | Designed nominal geometry
pack_protection | 1S2P pack protection allocation | 24.0 | 3.0 | 1.4 | -22.0 | 8.5 | 0.7 | Designed nominal geometry
pack_protection_pad | Pack protection adhesive pad | 23.0 | 2.5 | 0.3 | -21.5 | 8.75 | 0.4 | Designed nominal geometry
case_screw_1 | M1.6 × 5 case screw 1 | 3.21198 | 3.21234 | 5.00663 | -26.60563 | 60.09383 | 3.29972 | Designed nominal geometry
case_screw_2 | M1.6 × 5 case screw 2 | 3.21198 | 3.21234 | 5.00663 | 23.39437 | 60.09383 | 3.29972 | Designed nominal geometry
case_screw_3 | M1.6 × 5 case screw 3 | 3.21198 | 3.21234 | 5.00663 | -30.60563 | 8.39383 | 3.29972 | Designed nominal geometry
case_screw_4 | M1.6 × 5 case screw 4 | 3.21198 | 3.21234 | 5.00663 | 27.39437 | 2.39383 | 3.29972 | Designed nominal geometry
case_screw_5 | M1.6 × 5 case screw 5 | 3.21198 | 3.21234 | 5.00663 | 27.39437 | -27.60617 | 3.29972 | Designed nominal geometry
case_screw_6 | M1.6 × 5 case screw 6 | 3.21198 | 3.21234 | 5.00663 | -1.80563 | -62.60617 | 3.29972 | Designed nominal geometry
case_screw_7 | M1.6 × 5 case screw 7 | 3.21198 | 3.21234 | 5.00663 | -25.60563 | -62.80617 | 3.29972 | Designed nominal geometry
carrier_screw_1 | M1.4 × 3 retainer screw 1 | 2.20049 | 2.20074 | 3.60072 | -26.1 | 10.19963 | 1.54978 | Designed nominal geometry
carrier_screw_2 | M1.4 × 3 retainer screw 2 | 2.20049 | 2.20074 | 3.60072 | 23.9 | 10.19963 | 1.54978 | Designed nominal geometry
carrier_screw_3 | M1.4 × 3 retainer screw 3 | 2.20049 | 2.20074 | 3.60072 | -24.1 | 57.59963 | 1.54978 | Designed nominal geometry
carrier_screw_4 | M1.4 × 3 retainer screw 4 | 2.20049 | 2.20074 | 3.60072 | 21.9 | 57.59963 | 1.54978 | Designed nominal geometry
usb_cover | Flush USB-C silicone cover / prototype | 0.45118 | 12.60118 | 6.00118 | 31.54941 | -16.29327 | 0.60441 | Designed nominal geometry
sd_cover | Flush SD silicone cover / prototype | 0.45051 | 13.20051 | 2.60051 | -32.00025 | 22.39975 | 5.09975 | Designed nominal geometry
jack_cover | Flush jack silicone cover / prototype | 6.50145 | 0.45291 | 6.50218 | 15.60915 | -64.00145 | 1.17139 | Designed nominal geometry

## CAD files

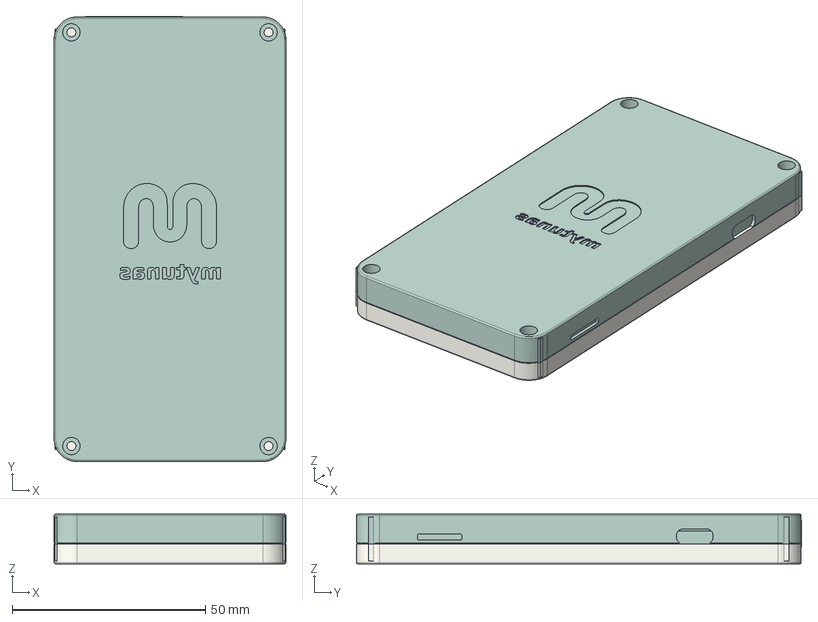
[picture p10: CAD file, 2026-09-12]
revision_04/designs/P04_compact/assembly_with_ASSUMED_components.step
60.0 x 115.1 x 12.9 mm
front_bezel
rear_shell
ASSUMED_display_envelope
ASSUMED_clickwheel_envelope
ASSUMED_battery_envelope
ASSUMED_clear_lens_reference
ASSUMED_fpc8
ASSUMED_xiao
ASSUMED_dac
ASSUMED_microsd

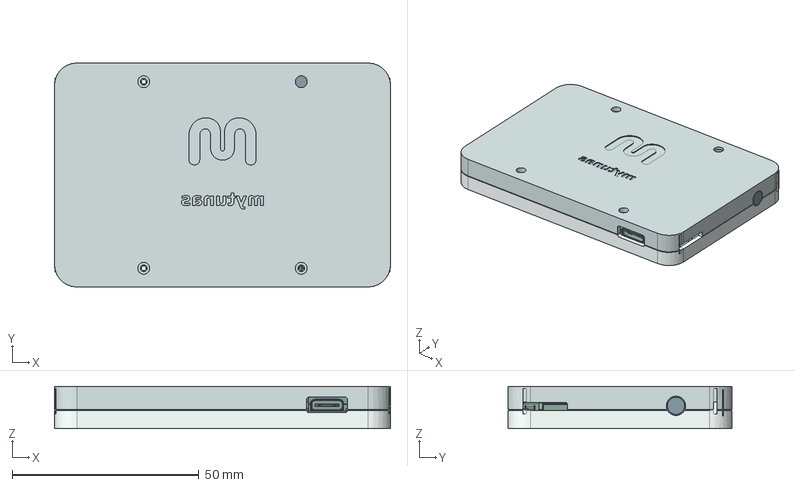
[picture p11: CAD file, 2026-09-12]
touchscreen_01/designs/T01_concept/assembly_ASSUMED_components.step
90.0 x 60.0 x 11.3 mm
front_bezel
rear_shell
battery_tray
ASSUMED_touch_glass
ASSUMED_touch_sensor
ASSUMED_touch_lcd_tape
ASSUMED_lcd
ASSUMED_battery
xiao
ASSUMED_audio
ASSUMED_interface_pcb
ASSUMED_microsd
ASSUMED_display_zif
ASSUMED_touch_zif
ASSUMED_control

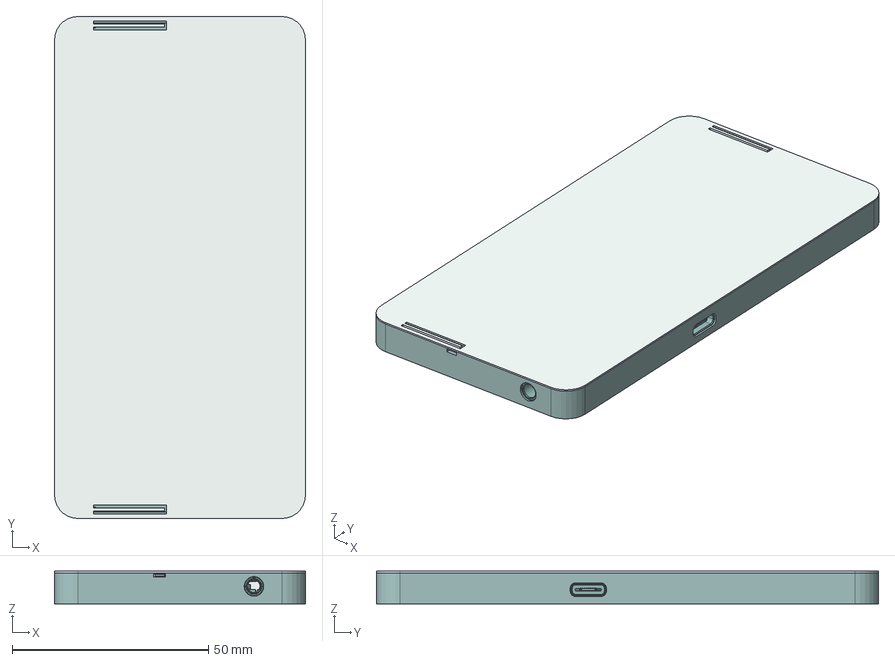
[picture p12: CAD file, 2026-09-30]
touchscreen_02/pla_fit/assembly_REFERENCE_ONLY.step
64.0 x 128.0 x 8.30 mm
touch_glass
lcd
audio
xiao
cell_A_envelope
cell_B_envelope
microsd_pcb
microsd_socket
microsd_card
interface_pcb
display_zif
touch_zif
interface_control
pack_protection
display_adhesive
display_cushion
audio_insulator
cell_A_envelope_adhesive
cell_B_envelope_adhesive
pack_protection_pad
xiao_saddle_pad
gate_tape
front_tray
rear_lid
carrier
xiao_gate

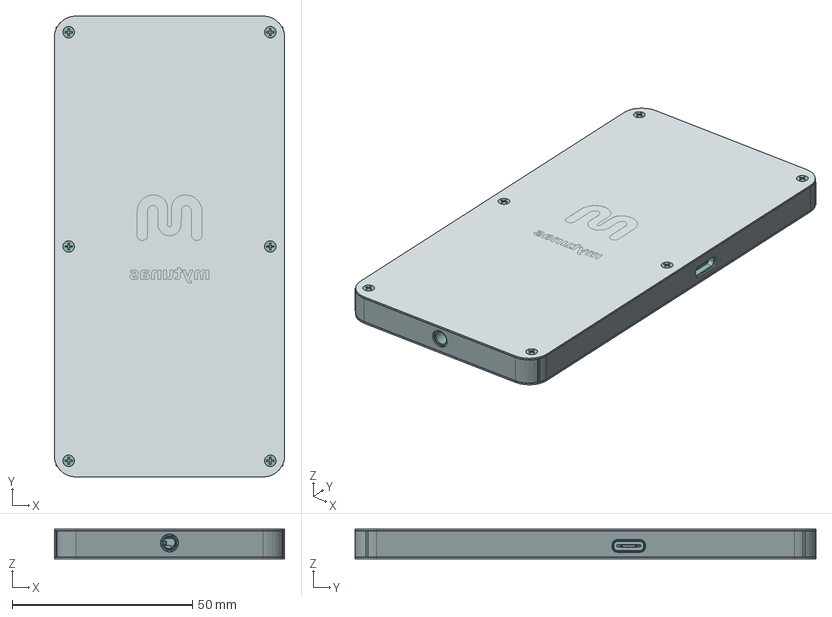
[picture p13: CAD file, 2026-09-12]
touchscreen_metal/designs/T03_metal/assembly_NOMINAL_components.step
64.0 x 128.0 x 8.30 mm
front_bezel
rear_shell
midframe
display_carrier
touch_glass
touch_sensor
touch_lcd_tape
lcd
display_adhesive
xiao
audio
battery
battery_foam
microsd
interface_pcb
display_zif
touch_zif
control
display_flex
touch_flex
audio_insulator
xiao_insulator
microsd_insulator
front_bond
rear_gasket
dac_retention
rear_liner
case_screws
carrier_screws

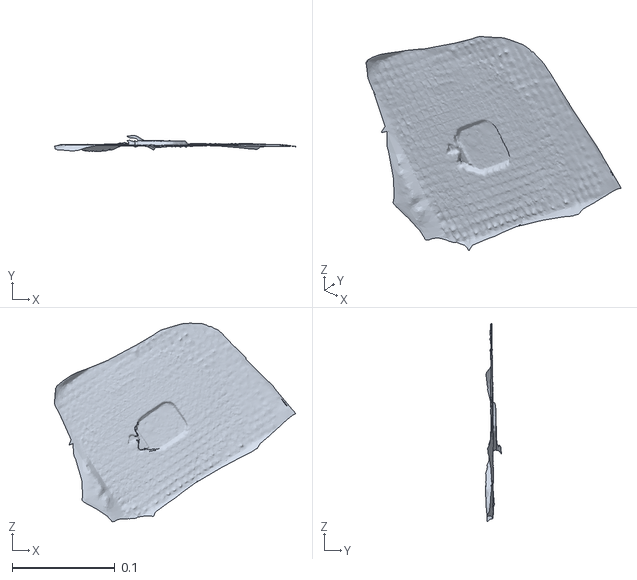
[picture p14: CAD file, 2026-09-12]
revision_04/designs/P04_compact/reference_only/Scaniverse_2026_09_12_145606.obj
0.235 x 0.0159 x 0.193

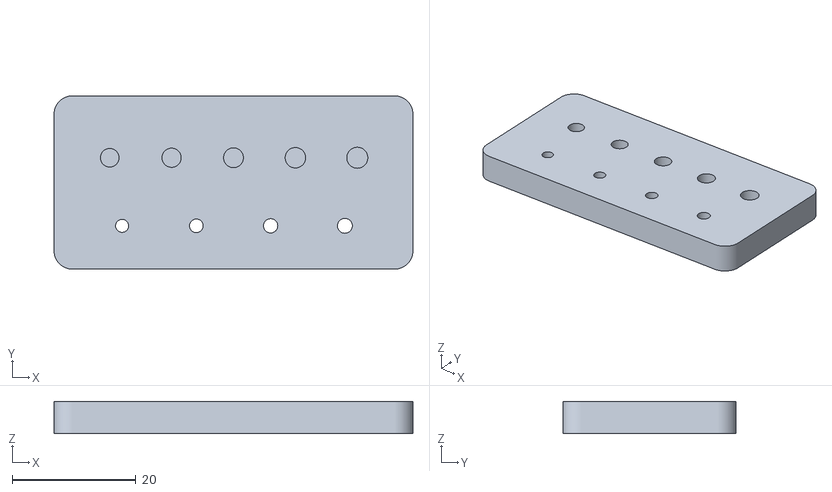
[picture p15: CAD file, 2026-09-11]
revision_04/designs/P04_compact/STL/insert_and_clearance_fit_coupon.stl
58.0 x 28.0 x 5.20

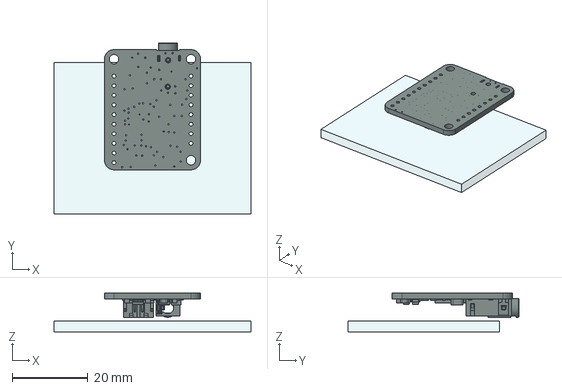
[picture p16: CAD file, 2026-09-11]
revision_04/studies/dac_orientation/current_REFERENCE_ONLY.step
52.0 x 45.2 x 10.2 mm
unaltered_vendor_DAC
assumed_LCD

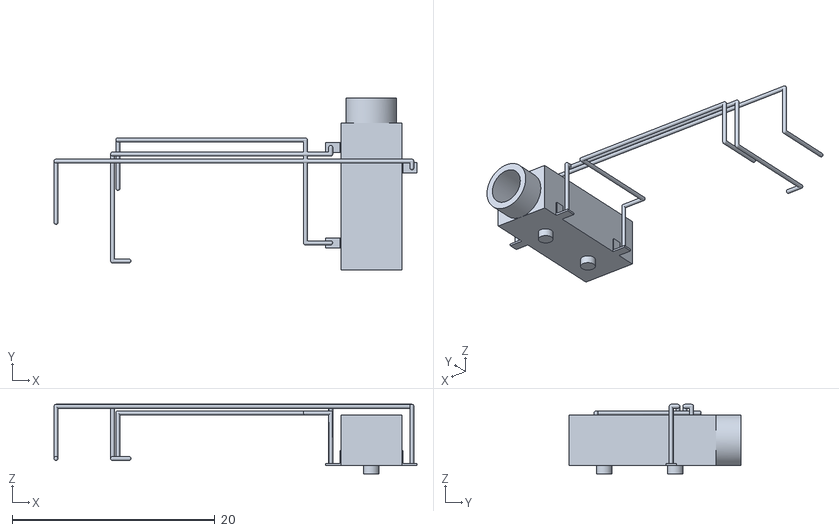
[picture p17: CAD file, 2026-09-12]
revision_04/studies/detached_jack/reference_only/headphone_jack.stl
35.8 x 17.0 x 6.85

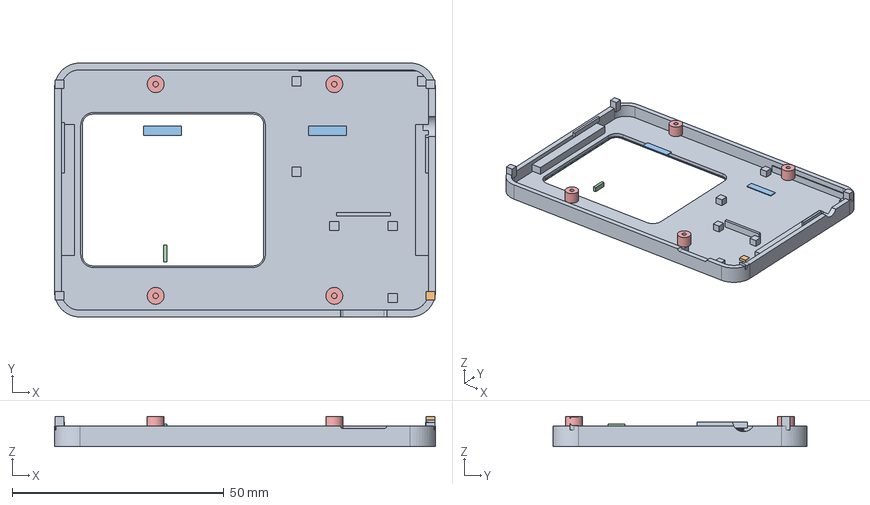
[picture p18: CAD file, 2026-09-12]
touchscreen_01/designs/T01_concept/front_bezel.step
90.0 x 60.0 x 7.10 mm

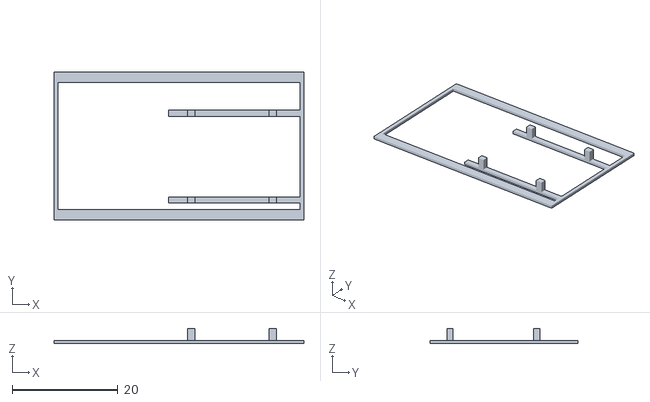
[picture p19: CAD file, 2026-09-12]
touchscreen_01/designs/T02_bottom_jack/STL/display_carrier_FIT_PROTOTYPE.stl
47.2 x 28.0 x 2.90

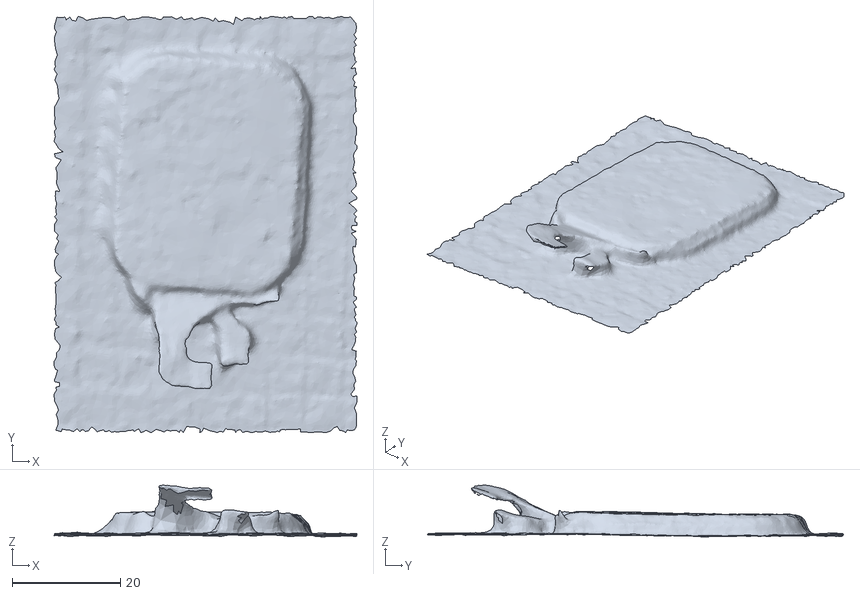
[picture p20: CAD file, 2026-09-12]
touchscreen_01/scan/leveled_crop_mm.ply
56.0 x 77.0 x 9.57

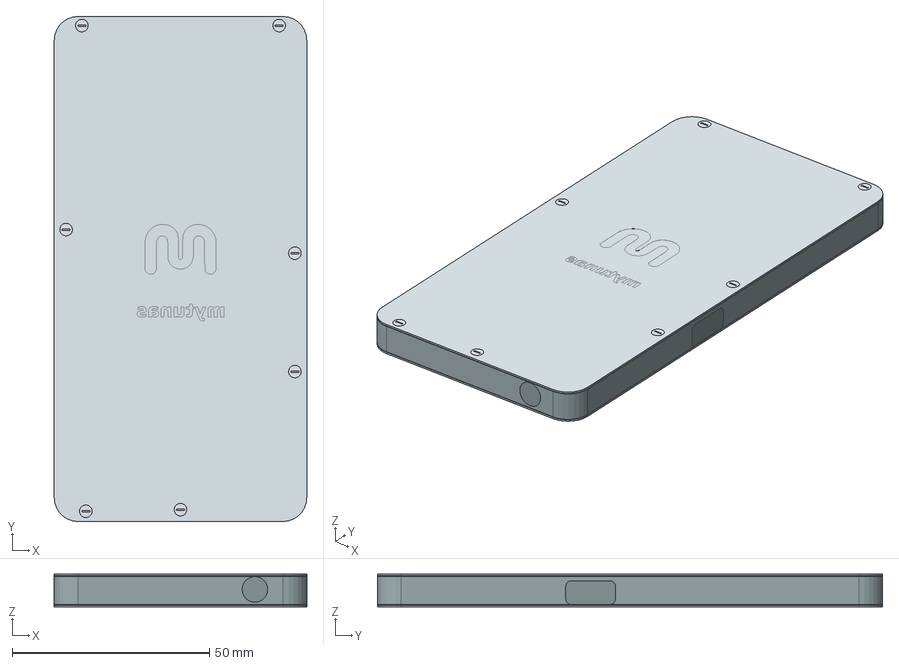
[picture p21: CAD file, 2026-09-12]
touchscreen_02/packing_REFERENCE_ONLY.step
64.0 x 128.0 x 8.30 mm
midframe
front_bezel
rear_shell
front_bond
rear_gasket
touch_glass
lcd
display_adhesive
display_carrier
display_cushion
carrier_rib_15
carrier_rib_15_bond
carrier_rib_56
carrier_rib_56_bond
audio
xiao
audio_insulator
xiao_insulator
xiao_insertion_stop
xiao_stop_adhesive
dac_insertion_stop
dac_stop_adhesive
dac_retainer_1
dac_retainer_bond_1
dac_retainer_2
dac_retainer_bond_2
dac_retainer_3
dac_retainer_bond_3
rear_liner
cell_A_envelope
cell_A_envelope_adhesive
cell_B_envelope
cell_B_envelope_adhesive
microsd_pcb
microsd_socket
microsd_card
sd_mount_pad
sd_stop_19_5
sd_stop_19_5_bond
sd_stop_38_5
sd_stop_38_5_bond
sd_insertion_stop
sd_insertion_stop_bond
interface_pcb
interface_pad_24
interface_pad_54
display_zif
touch_zif
interface_control
pack_protection
pack_protection_pad
case_screw_1
case_screw_2
case_screw_3
case_screw_4
case_screw_5
case_screw_6
case_screw_7
carrier_screw_1
carrier_screw_2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

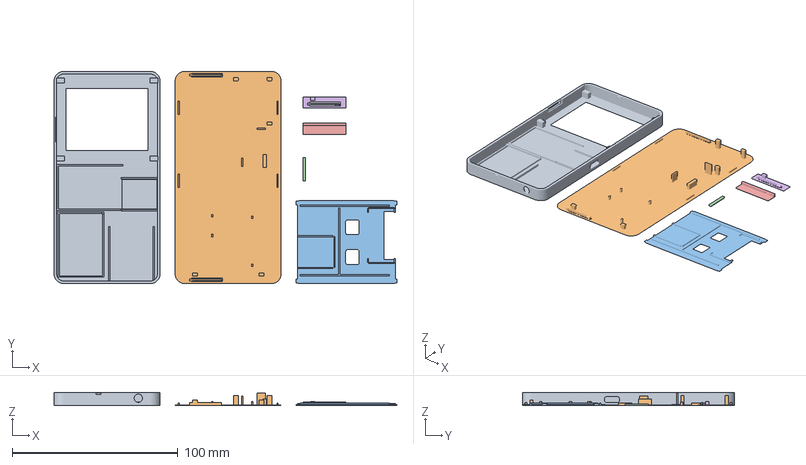
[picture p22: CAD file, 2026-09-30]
touchscreen_02/pla_fit/M02-P01_MK3S_PLA_UNSLICED.3mf
206.8 x 128.0 x 7.90 mm
front_tray
rear_lid
carrier
xiao_gate
coupon_receiver
coupon_lid

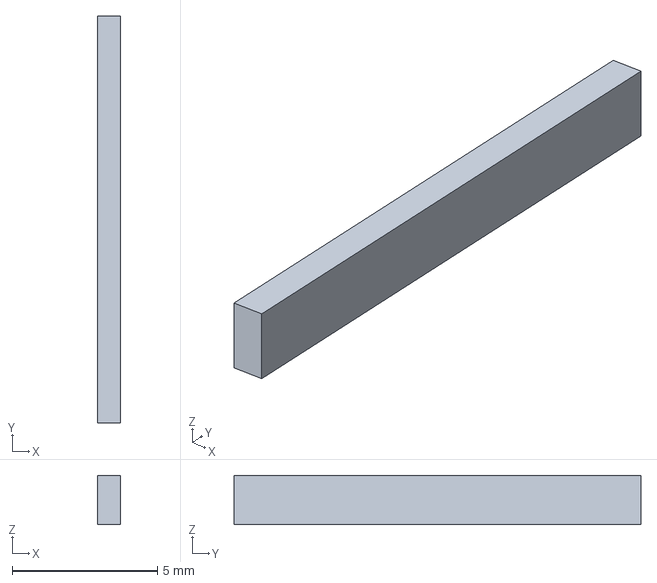
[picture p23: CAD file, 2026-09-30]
touchscreen_02/pla_fit/parts/xiao_gate.step
0.8 x 14.0 x 1.70 mm

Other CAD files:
touchscreen_01/designs/T01_concept/STL/front_bezel_FIT_CONCEPT.stl
touchscreen_metal/designs/T03_metal/display_carrier.step
touchscreen_metal/designs/T03_metal/reference_only/midframe.stl
touchscreen_metal/designs/T03_metal/STL/midframe_FIT_PROTOTYPE.stl
revision_04/designs/P04_compact/STL/front_bezel.stl
revision_04/designs/P04_compact/STL/rear_shell.stl
revision_04/designs/P04_compact/clear_lens_0p6_REFERENCE.dxf
revision_04/designs/P04_compact/front_bezel.step
revision_04/designs/P04_compact/rear_shell.step
revision_04/designs/P04_compact/reference_only/adafruit_6309_placed_VENDOR.step
revision_04/designs/P04_compact/reference_only/battery_envelope.stl
revision_04/designs/P04_compact/reference_only/clear_lens_reference.stl
revision_04/designs/P04_compact/reference_only/clickwheel_envelope.stl
revision_04/designs/P04_compact/reference_only/dac.stl
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

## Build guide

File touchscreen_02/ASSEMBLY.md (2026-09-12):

# M02-03 assembly and service

Coordinates refer to `designs/M02_03/assembly_NOMINAL.step`. Front exterior is Z0; rear exterior is Z8.3. This is a nominal prototype instruction, not a qualified production process.

1. **Measure incoming parts.** Compare boards, solder, screen/flexes and the approved pack against `COMPONENT_DIMENSIONS.md` and `measurements.csv`. Check flatness, deburr and insulate internal metal edges. Inspect DAC hole annuli and XIAO shield before accepting their proposed contact zones.
2. **Prepare the frame before electronics.** Use `midframe_BEFORE_HEAT_INSERTS.step` or its PA12 fit-test STL. Its insertion pilots are 2.15 mm; the assembled frame STEP depicts displaced material around installed inserts. Install seven PEM MSIB-M1.6-300 and six MSIB-M1.4-150 candidates using the supplier's heat/ultrasonic process before bonding in glass. Qualify PA12, hole tolerance, retention and screw torque on a coupon. All sites have at least 4.2 mm nominal boss diameter; supplier maximum insert OD is 2.6 mm.
3. **Prepare the steel carrier.** Laser seam weld four 0.30 mm blades to the 0.20 mm web in a flat fixture. STEP represents fused joints, not a developed sheet pattern or weld schedule. Inspect for distortion and sharp edges. Prepare SD edge stops and insulating board lands as a replaceable carrier subassembly. Keep the SD insertion stop off until its board is seated.
4. **Bond front and display.** Fit the 0.15 mm front perimeter bond, then the display's 0.15 mm perimeter bond. Lower the verified screen from the rear. Align the active area before committing the adhesive. Actual FPC bends and permitted glass support zones require a sample trial.
5. **Install the XIAO.** Lay in its removable 0.35 mm dielectric seat. Keep the side stop and saddle out. Start 1.6 mm inward, lower, then slide USB toward the right opening. Fit the side stop using its replaceable 0.15 mm pad. Place the installed 0.30 mm cushion on the shield at X22/Y−10 and fasten the steel saddle with two M1.4 × 3 screws into metal inserts. Qualify compression and shield loading; no torque has been established.
6. **Install the DAC.** Lay its removable 0.15 mm dielectric sheet on the front. Start the intact board 2 mm above its final Y position, lower and slide the jack toward the bottom. Fit three insulating shoulder/locating seats into the original holes, with 0.10 mm nominal radial clearance. These seats remain on the board when rear columns lift. The PCB and jack are unchanged; no glued DAC backstop is needed.
7. **Fit the display carrier.** Install its LCD cushion, route qualified tails through the relief, and fit four M1.4 × 3 screws into metal inserts. Central windows provide inspection access. Check all screws remain accessible without loading glass or moving boards.
8. **Install upper boards.** The provisional SD board lowers 1.6 mm inward, slides left, then seats on its 0.30 mm insulating pad. Fit its insertion stop afterwards. The interface PCB mounts on two insulating lands. Final PCBs, connectors and adhesive removal methods remain unqualified. These boards can be serviced as a carrier subassembly; do not invent holes in purchased hardware.
9. **Install the approved battery assembly.** Fit two replaceable 0.30 mm insulating retention pads and the supplier-designed matched 1S2P pack. Keep both 1.70 mm expansion reserves empty. Do not add metal straps or rear compression foam over pouches. Qualify the pad removal method before production.
10. **Connect and test.** Use reserved lead passages and secure strain relief. Harness and service disconnect are not yet completed electronics. Verify charging, audio, SD, display and touch before closing.
11. **Prepare the rear.** Attach three custom threaded stainless DAC columns with M1.4 × 3 countersunk screws through the rear sheet. Countersinks continue into the columns; the 0.40 mm sheet alone does not contain the full heads. Fit the dielectric liner around column cutouts. Columns have no adhesive-only attachment to the lid.
12. **Close.** Fit the installed 0.15 mm rear gasket and lower the lid so columns seat on the DAC's insulating shoulders. Fit seven M1.6 × 5 perimeter screws into metal inserts gradually and alternately. Frame stops define Z7.90. Verify the DAC's 0.18 mm nominal roof gap and no plate bow. Repeated opening must not crush the gasket or disturb columns.
13. **Check ports and optional covers.** Verify full plug/card seating and no rubbing. Each uncovered opening has positive mating clearance. Qualify covers separately; no water-resistance rating is established.

## Replacement order

Disconnect USB, remove seven perimeter screws and lift the rear with its attached DAC columns. Disconnect the approved battery pack before working on boards. Leave the three column-to-rear screws installed during routine opening.

| Part | Access / removal |
|---|---|
| Rear gasket / liner | Exposed when lid lifts; inspect and replace if damaged |
| DAC | Disconnect wiring; remove locating seats, slide 2 mm upward, then lift; retain dielectric sheet |
| XIAO saddle | Remove two M1.4 screws and lift; path clears installed batteries and carrier |
| XIAO board | Disconnect wiring; remove battery A by its approved adhesive procedure, remove saddle and side stop, slide 1.6 mm inward, then lift |
| Battery assembly | Disconnect pack and release both pads by the qualified supplier method; no rigid clips cross pouches |
| SD / interface | Disconnect tails, remove four carrier screws and service carrier subassembly; replace disturbed pads |
| Display | Remove carrier and release perimeter bond using a qualified glass-safe process |

Ordinary small slotted drivers fit the nominal screw models; final screw drive/head drawings must be selected and checked. Insert retention, welded joints, shield loading, plug loads, gasket life and repeated servicing need physical cycle tests before a multi-year durability claim.

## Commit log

2026-09-11 P04: MP3 player enclosure with interactive 3D preview
    134 × 72 × 13.4 mm printable enclosure for XIAO ESP32-S3, ST7789 display,
    iPod clickwheel, Adafruit TLV320DAC3100 DAC/headphone board, and 600 mAh cell.
    Includes standalone WebGL viewer with procedural iPod-style Now Playing UI,
    exploded assembly controls, and part visibility toggles.
    [BOM.csv, adafruit_6309_placed_VENDOR.step, assembly_with_ASSUMED_components.step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]
2026-09-11 Ignore old revisions and root P01 files — only revision_04 is tracked
2026-09-11 Replace primitive box components with detailed parametric 3D models
    [battery_envelope.stl, dac.stl, fpc8.stl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]
2026-09-11 Fix build.py overwriting detailed component models with primitive boxes
    [battery_envelope.stl]
2026-09-11 Fix component coordinates in parametric generation script
    [battery_envelope.stl, fpc8.stl, microsd.stl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]
2026-09-11 Update rear shell, BOM, viewer layout, and branding assets
    [BOM.csv, assembly_with_ASSUMED_components.step, rear_shell.step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]
2026-09-11 Comprehensive update to component geometries, assembly, CAD validation, and viewer
    [BOM.csv, adafruit_6309_placed_VENDOR.step, assembly_with_ASSUMED_components.step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]
2026-09-11 Update enclosure studies, hardware notes, and viewer configurations
    [BOM.csv, adafruit_6309_placed_VENDOR.step, assembly_with_ASSUMED_components.step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]
2026-09-11 Add cross-section and bottom port views, update drawings and models
    [BOM.csv, adafruit_6309_placed_VENDOR.step, assembly_with_ASSUMED_components.step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]
2026-09-12 Update repository with latest changes
    [adafruit_6309_placed_VENDOR.step, assembly_with_ASSUMED_components.step, clear_lens_0p6_REFERENCE.dxf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]
2026-09-12 Update README and add new models
    [BOM.csv, Scaniverse_2026_09_12_145606.obj, assembly_ASSUMED_components.step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]
2026-09-12 Update touchscreen_01 design files, viewer, and add scan images
    [assembly_ASSUMED_components.step, audio.stl, battery.stl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]
2026-09-12 Add T02 bottom jack design and update viewer files
    [BOM.csv, assembly_NOMINAL_components.step, audio.stl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]
2026-09-12 Add touchscreen_metal design and update README
    [BOM.csv, assembly_NOMINAL_components.step, audio.stl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]
2026-09-12 Update touchscreen_metal design and add studies
    [assembly_NOMINAL_components.step, display_carrier.step, display_carrier_profile.dxf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]
2026-09-12 Promote compact Model 02 touchscreen layout with bottom jack and dual battery envelopes
    [packing_REFERENCE_ONLY.step]
2026-09-12 Update touchscreen_02 design and viewer files
    [BOM.csv, assembly_NOMINAL.step, audio.stl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]
2026-09-12 Update touchscreen_02 with M02_03 design
    [BOM.csv, audio.stl, audio_insulator.stl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]
2026-09-23 chore: regenerate CAD design files and assembly models
    [cell_A_envelope_adhesive.dxf, cell_B_envelope_adhesive.dxf, dac_retainer_1.step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]
2026-09-30 feat(touchscreen_02): add M02-P01 PLA fit prototype branch and documentation
    [KR3_REMADE_standard_6mmD_PROVISIONAL.stl, M02-P01_MK3S_PLA_UNSLICED.3mf, assembly_REFERENCE_ONLY.step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]
2026-10-07 feat: add DIY shopping list, wiring guide, electronics plan, and ordering audit documentation
2026-10-16 refactor: update CAD parts, STEP models, and mesh previews for touchscreen assembly
2026-10-16 feat: update 3D model geometry and assembly specifications for PLA fit enclosure
2026-11-04 docs(hardware): add documentation and bring-up sketch for salvaged watch LCD and touch probe
2026-11-05 feat: add lcd pin finder and wire check utilities with documentation
2026-11-05 docs: document abandoned watch screen probe and wire check results
